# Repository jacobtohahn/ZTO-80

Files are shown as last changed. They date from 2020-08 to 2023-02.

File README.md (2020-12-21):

# ZTO-80
The ZTO-80 is a capable and highly expandable line of Z80 computers and peripherals.

[Hackaday](https://hackaday.io/project/167253-zto-80-modular-computer-system)

## Design
The ZTO-80 is built around the Zilog Z80 CPU, which was designed in 1976. It is still in production today, and, like the 6502, has found its place among hobbyists, particularly within the scope of vintage computing.

The system has two main designs: the SBC and the Modular System.
The ZTO-80 SBC is perfect for those wanting to get started developing with the Z80, both in hardware and software, while the Modular System is built from the ground up to be fully customizable, making it the perfect prototyping environment for more experienced developers.

### SBC
The ZTO-80 Single Board Computer, as the name implies, consists of only one PCB containing all essential system ICs along with I/O. This makes it cheaper and more compact than a multi-board system, with the downside being that it lacks the flexibility and customization it would have otherwise. My design addresses this downside by providing as many on-board features as possible, while allowing customization through configuration headers and an expansion bus.

#### SBC Features:
- CPU: Zilog Z80, running at 4-20MHz (depending on the model and your crystal choice)
- Memory:
  - RAM: 32K
  - ROM: 32K (with optional BASIC interpreter)
- I/O:
  - SIO:
    - Two serial channels with programmable baud rates
  - PIO:
    - Two 8-bit parallel ports, one with a darlington transistor array for high current output
  - CTC:
    - Four timers with external triggers

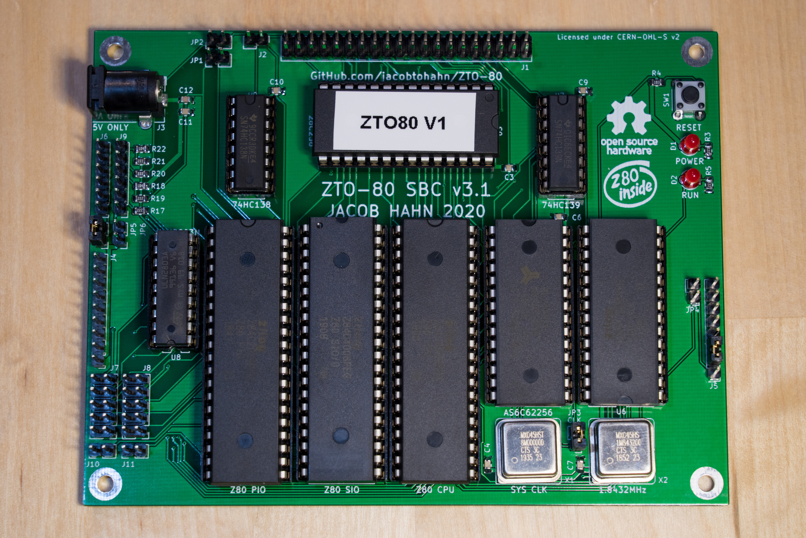
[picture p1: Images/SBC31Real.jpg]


### Modular System
The ZTO-80 Modular System is a multi-board system allowing ultimate customization and expansion. The system is built out of *modules* and a *backplane*. The modules contain individual pieces of a ZTO-80 computer system (such as the CPU, memory, serial I/O, etc). The backplane provides power and ties all of the modules together. A bus provides a standardized interface for modules to communicate with each other and connect to the backplane.

The main advantage of a modular system is flexiblilty. A user can install or remove individual features, or can create new features in the form of modules. This allows rapid prototyping and troubleshooting. Also, due to increased board space, more customization options can be implemented into individual modules.

Currently, work on the modular system is paused while I finish designing and testing the latest version of the SBC.

#### Official ZTO-80 Modular System modules:
- ZTO-80 Backplane 5
- ZTO-80 CPU
- ZTO-80 Memory
- ZTO-80 SIO
- ZTO-80 PIO (to be designed)
- ZTO-80 CTC

## How I use this repository
This repository keeps all of the PCB files and code for the ZTO-80. To keep things simple for me, I will update this repository each time I make a major change to an aspect of the design, either to the PCB or the code. I will also release minor fixes to the design.

## Contact
If you need to contact me for any reason, the best way is through my email, jtohahn@gmail.com.

You can also try to reach me through a private message on Hackaday.io, but there is no guarantee that I will see it.

## License
Copyright Jacob Hahn 2020.

This source describes Open Hardware and is licensed under the CERN-OHLS v2.
You may redistribute and modify this hardware and make products
using it under the terms of the CERN-OHL-S v2 (https:/cern.ch/cern-ohl).
This hardware is distributed WITHOUT ANY EXPRESS OR IMPLIED
WARRANTY, INCLUDING OF MERCHANTABILITY, SATISFACTORY QUALITY
AND FITNESS FOR A PARTICULAR PURPOSE. Please see the CERN-OHL-S v2
for applicable conditions.

Source location: https://github.com/jacobtohahn/ZTO-80

This documentation is released under the Attribution-ShareAlike 4.0 International License and is copyright Jacob Hahn 2020. You may use and share this documentation under the terms of the license, found here: https://creativecommons.org/licenses/by-sa/4.0/.

Please note that the CC-BY-SA License only applies to this project's documentation. Any other files, such as design files, are licensed under the terms of the CERN-OHL-S v2 license, as described above.

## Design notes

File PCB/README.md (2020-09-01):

# PCB
This directory contains the PCB files that I have created in KiCad so far, sorted as SBC PCBs and Modular System PCBs, along with any supporting documentation. The Modular System subdirectory contains a template for creating your own modules. See the READMEs in each subdirectory to get specific instructions for each board.

## Modular System Requirements
The three required boards for a working ZTO-80 Modular System are the Backplane, CPU board, and Memory board. Either the SIO or PIO board is required for output. The rest of the boards are optional and simply add additional features.

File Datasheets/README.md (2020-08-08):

# Datasheets
The subdirectories of this folder contain PDF datasheets for any ICs used.

Keep in mind that some pins may have slightly different names than what I used in my schematics, but it should be easy to tell which corresponds with which.

All datasheets included are not written by me and are copyrighted by their respective authors.

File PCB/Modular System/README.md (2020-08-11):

## Modular System PCBs
The subfolders in this directory contain the KiCad project files and additional files for Modular System boards. Look in each subfolder for information on each board and files.

## Component Notes
Unless stated otherwise in a README or silkscreen, always use CMOS ICs to build your system.

To bridge jumpers, I recommend using standard 0.1 in. jumper shunts.

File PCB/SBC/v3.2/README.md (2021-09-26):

# ZTO-80 SBC
This folder contains all the KiCad files for ZTO-80 SBC v3.2, along with an additional files and documentation.

This folder is a work in progress. The Getting Started guide has not been created yet. Check back soon!

## Additional files and subdirectories
- **PDF**: A subdirectory containing PDF files of the schematic and PCB.
- **Getting Started with the ZTO-80 SBC v3.2.pdf**: A getting started guide for the SBC v3.2.

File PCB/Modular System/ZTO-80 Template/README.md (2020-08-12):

# ZTO-80 Module Template
This directory contains a template file for creating your own ZTO-80 Modular System boards. There are comments in the PCB file itself, but this file will elaborate on some of them and add some design considerations.

## PCB Comments

### Module Title
This is the main title of the module, located on the front silkscreen of the board.
In general, you should try and keep the title short enough that the text is shorter than the width of the header below.

### Version
The revision of the PCB design, located on the front silkscreen of the board.
Start with v1.0.

### Designer and Year
The name of the board designer and the year the revision was made, located on the front silkscreen of the board.

### Module Reference
This text on the front silkscreen provides a quick way to find or identify a module when it is in a backplane. 
Oftentimes, other modules will prevent you from being able to see the main title of the module, so this reference is located at the top corner of the PCB, where it will not be blocked. 

### JLCPCB PN Reference
This text, located on the back silkscreen, is used if you choose to have your boards manufactured by JLCPCB.
It lets them know where you would like the Product Number text to be silkscreened. If you don't have the boards manufactured by JLCPCB, be sure to remove it!

### Component Keepout
This keepout lets your module be compatible with an enclosure that is currently in development.
There is a slot which the board edge fits into, so if there are any components within the area on the front or back of the PCB, the board will not be compatible with the enclosure.

## General Design Considerations
- When designing boards, I use a 25 mil grid. I recommend using the same.
- All of my boards use 10 mil trace/space. This is compatible with most fabs and also is small enough to fit traces between pins.

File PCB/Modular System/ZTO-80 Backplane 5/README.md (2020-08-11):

# ZTO-80 Backplane 5
This is the main backplane for the ZTO-80 Modular System. It includes 5 module slots, a power input jack and LED, a reset button, two headers for connecting an external power LED and reset switch, and six M3 mounting holes.

The power input supports 5V only. Anything over 5.5 volts could damage or destroy some ICs.

## Additional Files
- **PDF**: A subdirectory containing PDF files of the schematic and PCB.

## Component Notes
The ZTO-80 bus header slots should be female sockets.

I recommend using pan-head M3 machine screws with a washer to fasten the board with the mounting holes.

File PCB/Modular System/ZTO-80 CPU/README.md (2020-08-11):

# ZTO-80 CPU
This is the CPU module for the ZTO-80 Modular System, containing the Z80 CPU, system clock, reset button, address and data buffers, and a header for CPU signals.

## Additional Files
- **PDF**: A subdirectory containing PDF files of the schematic and PCB.

## Component Notes
It is recommended to use a CMOS Z80 and 74HCT logic ICs on this board.

While Z80s overclock well, it is recommended that the max clock speed matches the CPU's rated speed.

Use two pin headers as jumpers on this board.

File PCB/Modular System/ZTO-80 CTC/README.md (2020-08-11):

# ZTO-80 CTC
This is the CTC (Counter-Timer Circuit) board for the ZTO-80 Modular system. It contains the CTC, a DIP switch for setting the address, jumpers for setting the CTC configuration, and a pin header for outputting the CTC signals.

## Additional Files
- **PDF**: A subdirectory containing PDF files of the schematic and PCB.

## Component Notes
Use two pin male headers as the jumpers on this board.

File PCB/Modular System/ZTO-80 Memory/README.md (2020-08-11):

## ZTO-80 Memory
This is the memory board for the ZTO-80 Modular System. It contains the RAM and ROM chips.

## Additional Files
- **PDF**: A subdirectory containing PDF files of the schematic and PCB.

## Component Notes
The RAM chip should be 32K, and the ROM chip should be 32K.

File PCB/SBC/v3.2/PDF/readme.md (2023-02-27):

# !!! WARNING !!!
## These PDF files are not up to date while I rework my PDF generation workflow. To see the latest PCB, download and open the KiCAD PCB file.

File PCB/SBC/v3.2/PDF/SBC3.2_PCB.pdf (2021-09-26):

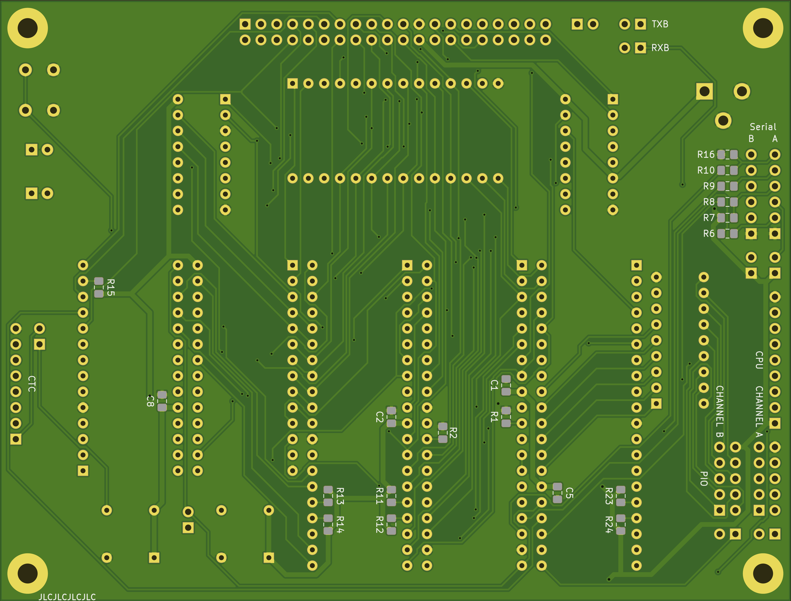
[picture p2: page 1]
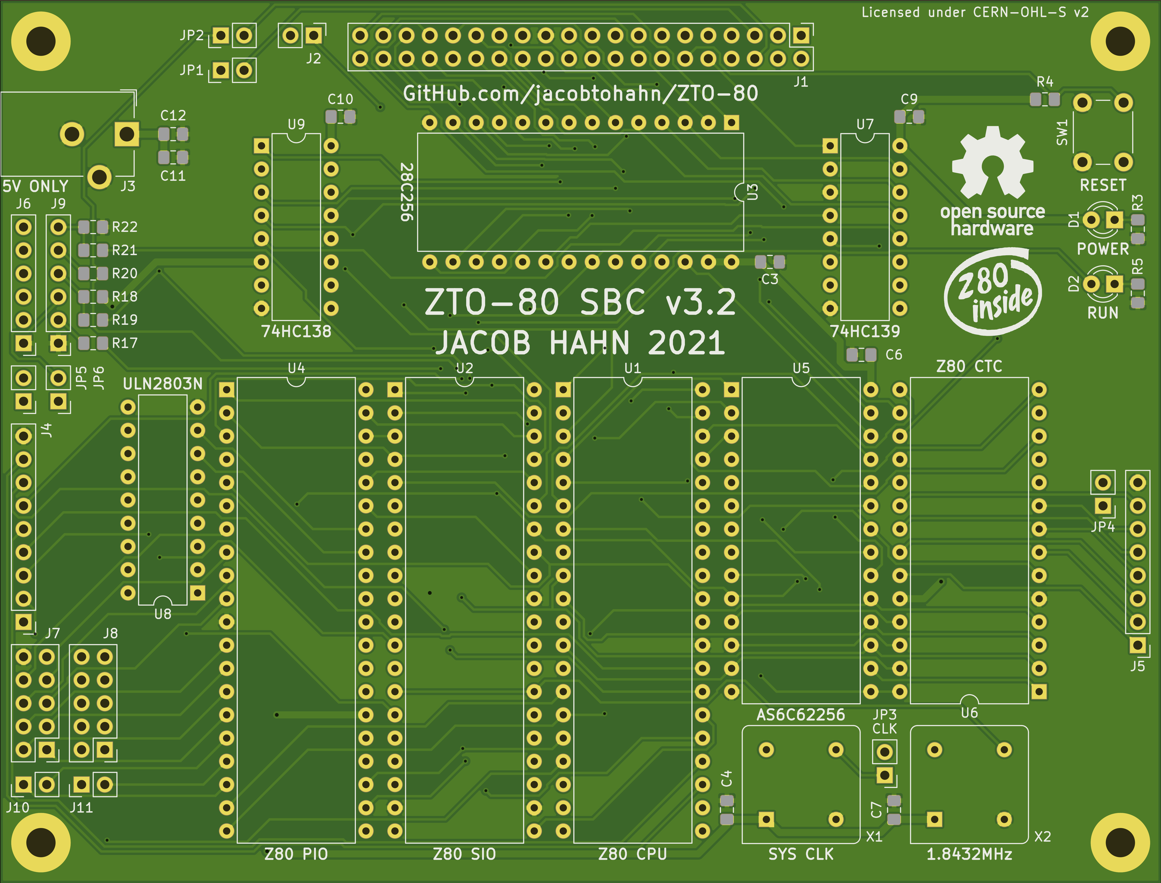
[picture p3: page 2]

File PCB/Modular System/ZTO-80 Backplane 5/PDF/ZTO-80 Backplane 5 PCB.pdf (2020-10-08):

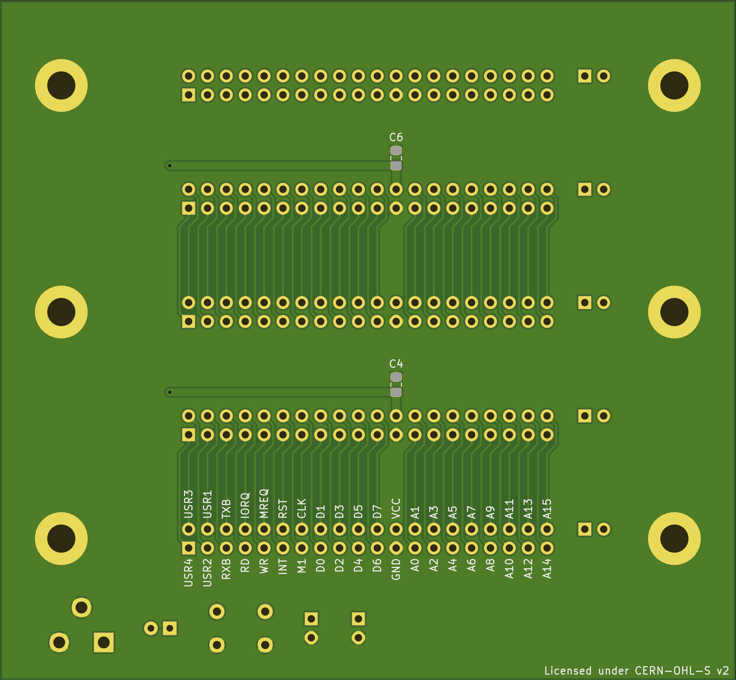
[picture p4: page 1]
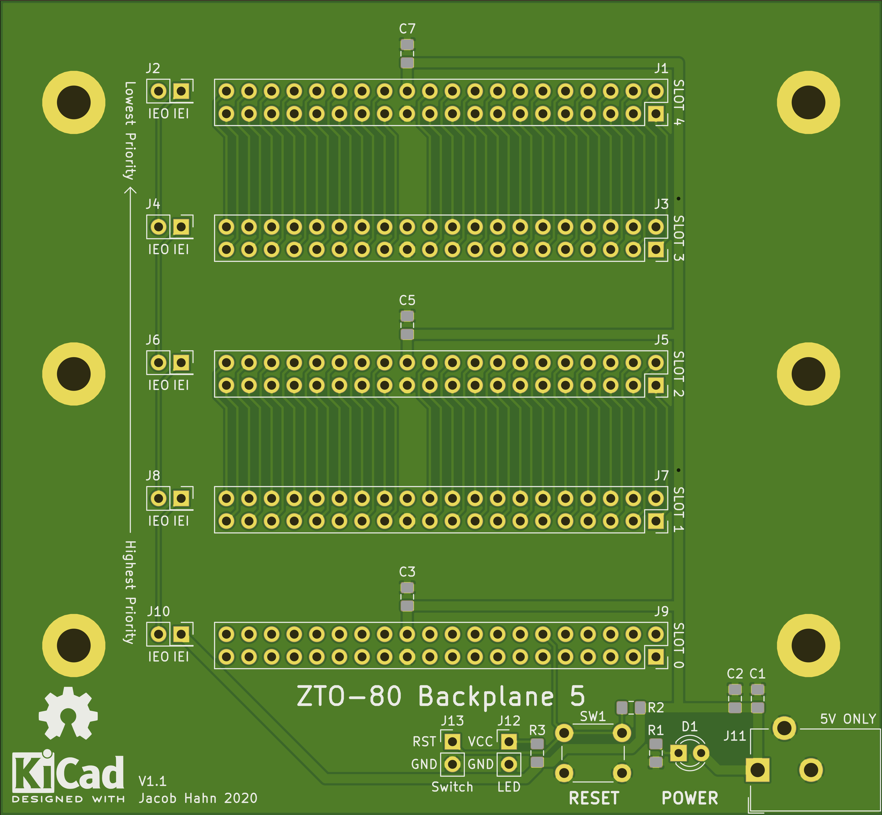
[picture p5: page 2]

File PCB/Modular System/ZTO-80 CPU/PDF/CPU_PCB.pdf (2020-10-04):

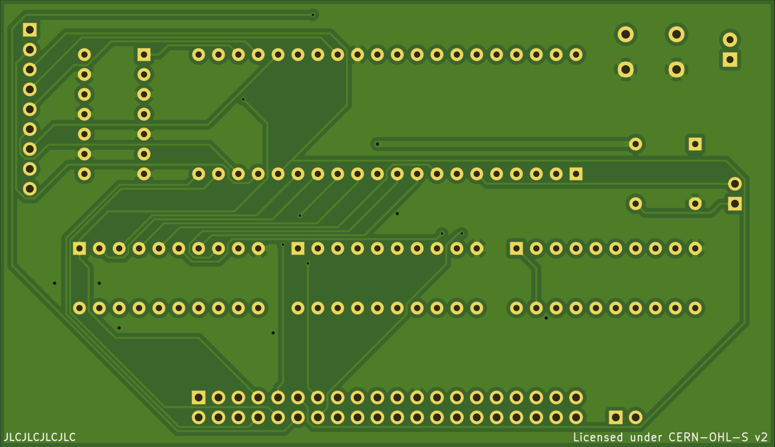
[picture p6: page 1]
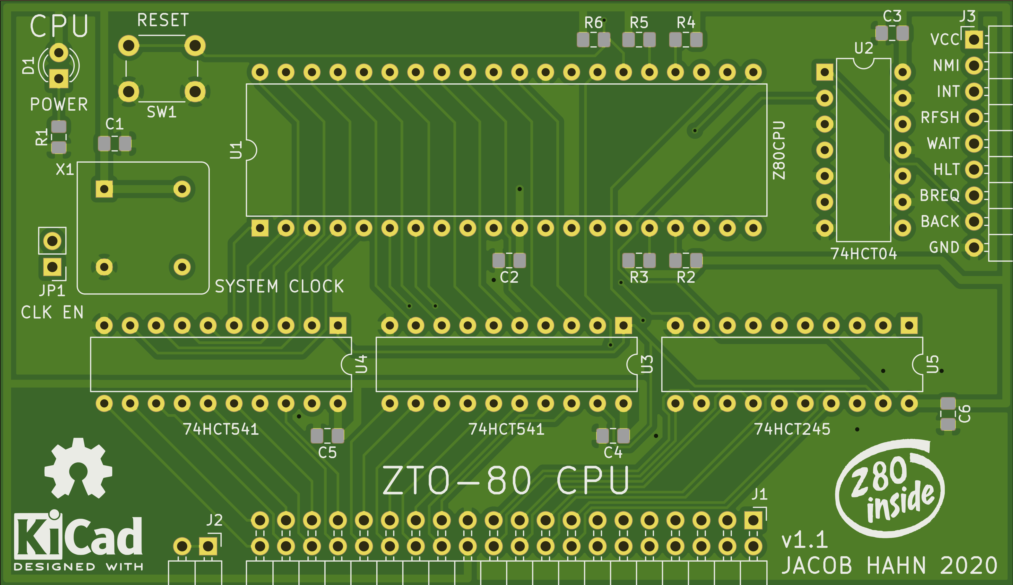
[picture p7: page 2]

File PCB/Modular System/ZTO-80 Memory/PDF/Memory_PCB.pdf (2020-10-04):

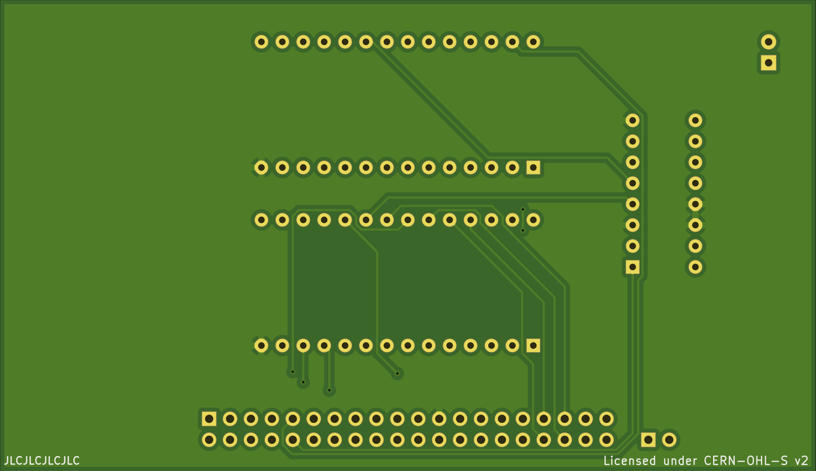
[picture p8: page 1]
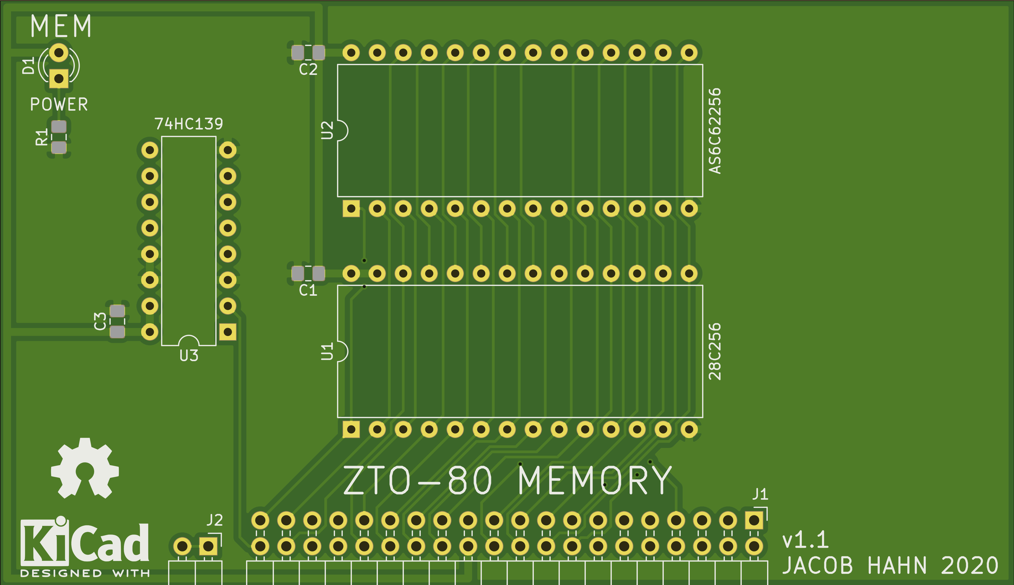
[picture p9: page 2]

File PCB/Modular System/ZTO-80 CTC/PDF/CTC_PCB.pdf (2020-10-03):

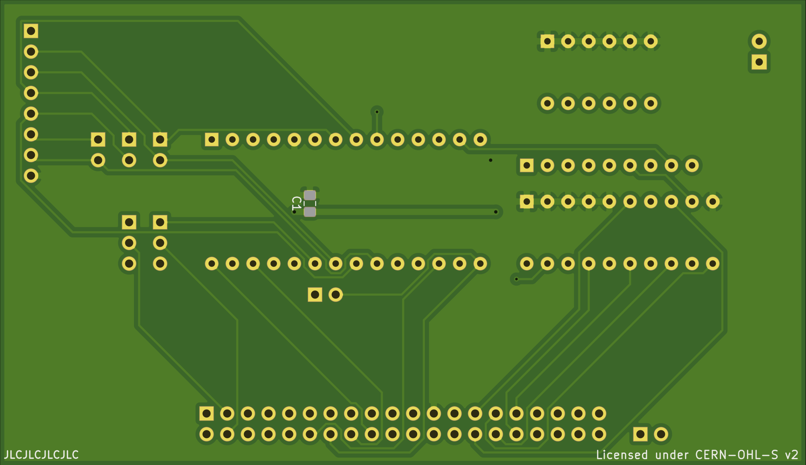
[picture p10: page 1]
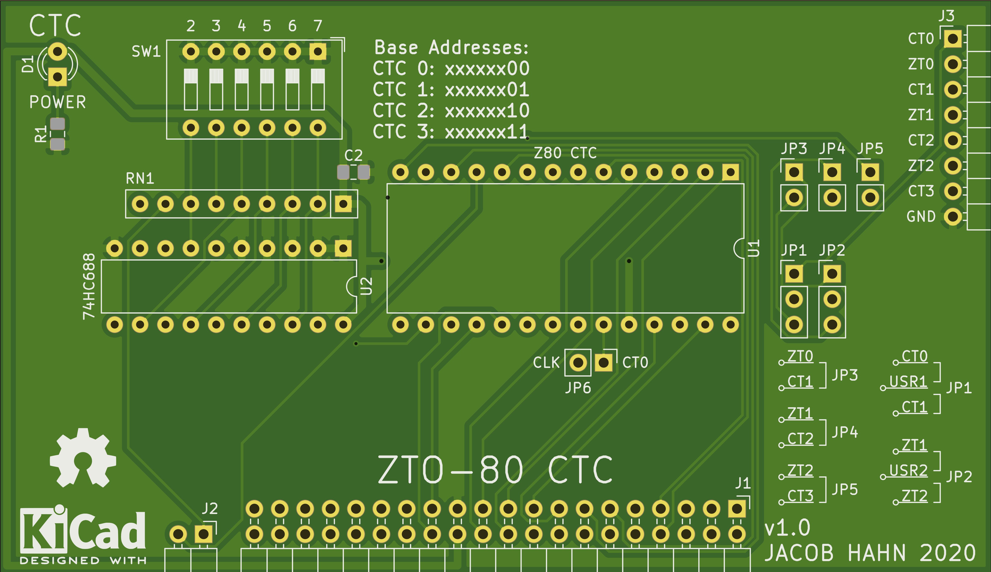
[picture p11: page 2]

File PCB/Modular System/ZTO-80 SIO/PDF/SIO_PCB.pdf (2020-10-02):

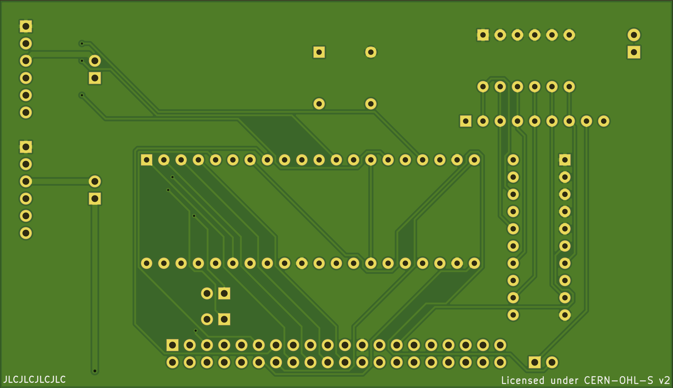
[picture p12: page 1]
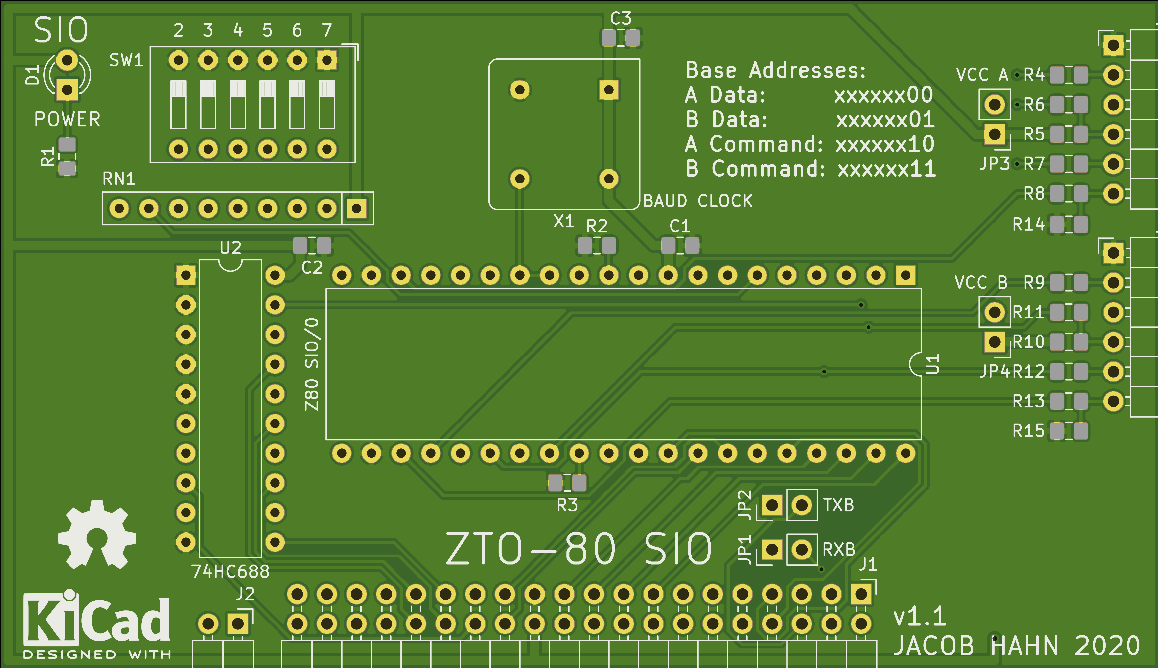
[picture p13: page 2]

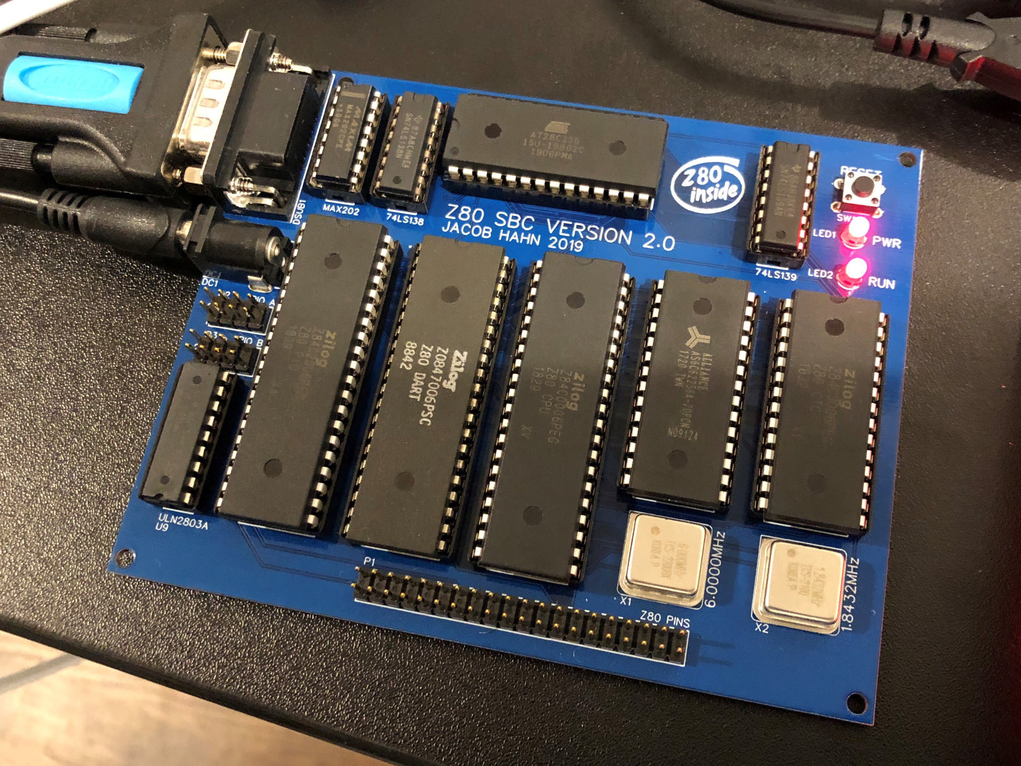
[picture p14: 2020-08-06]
Images/SBCv2.jpg

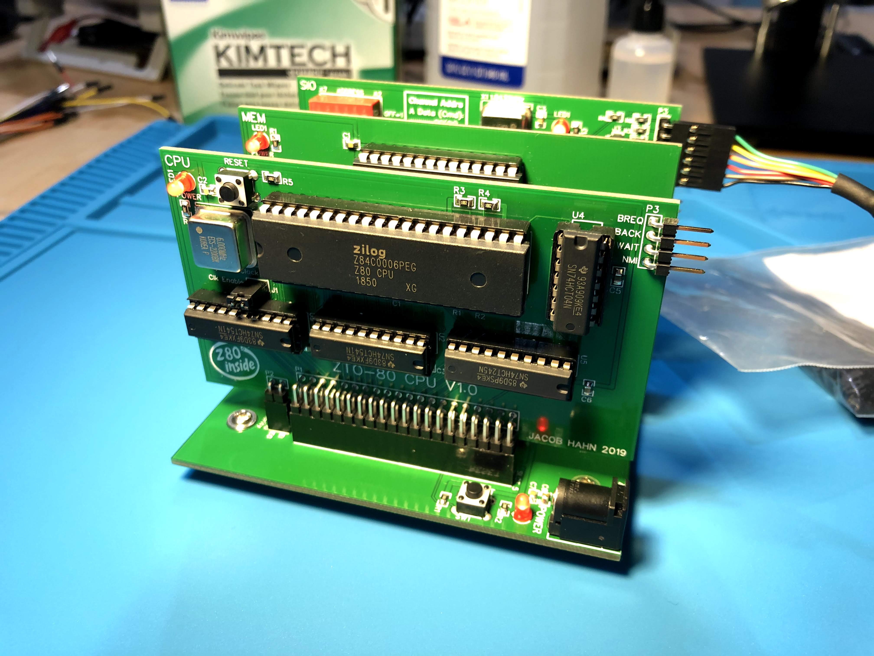
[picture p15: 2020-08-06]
Images/Mod3.jpg

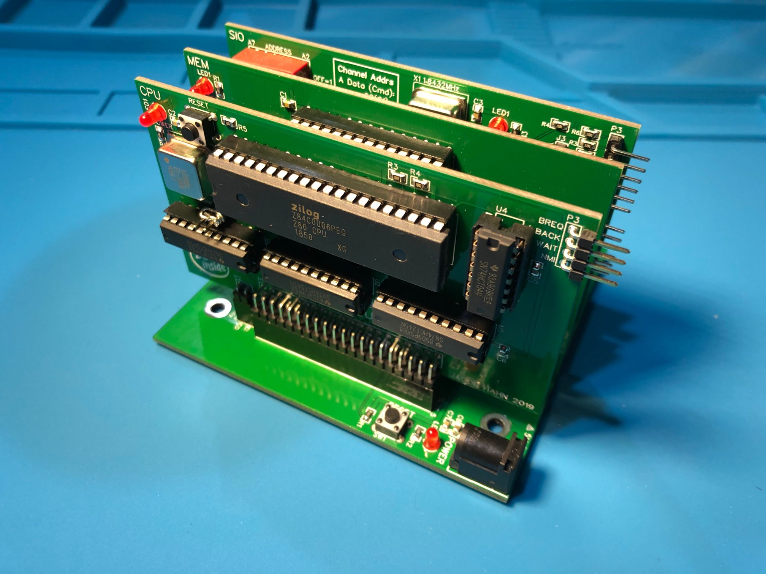
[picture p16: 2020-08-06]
Images/Mod1.jpg

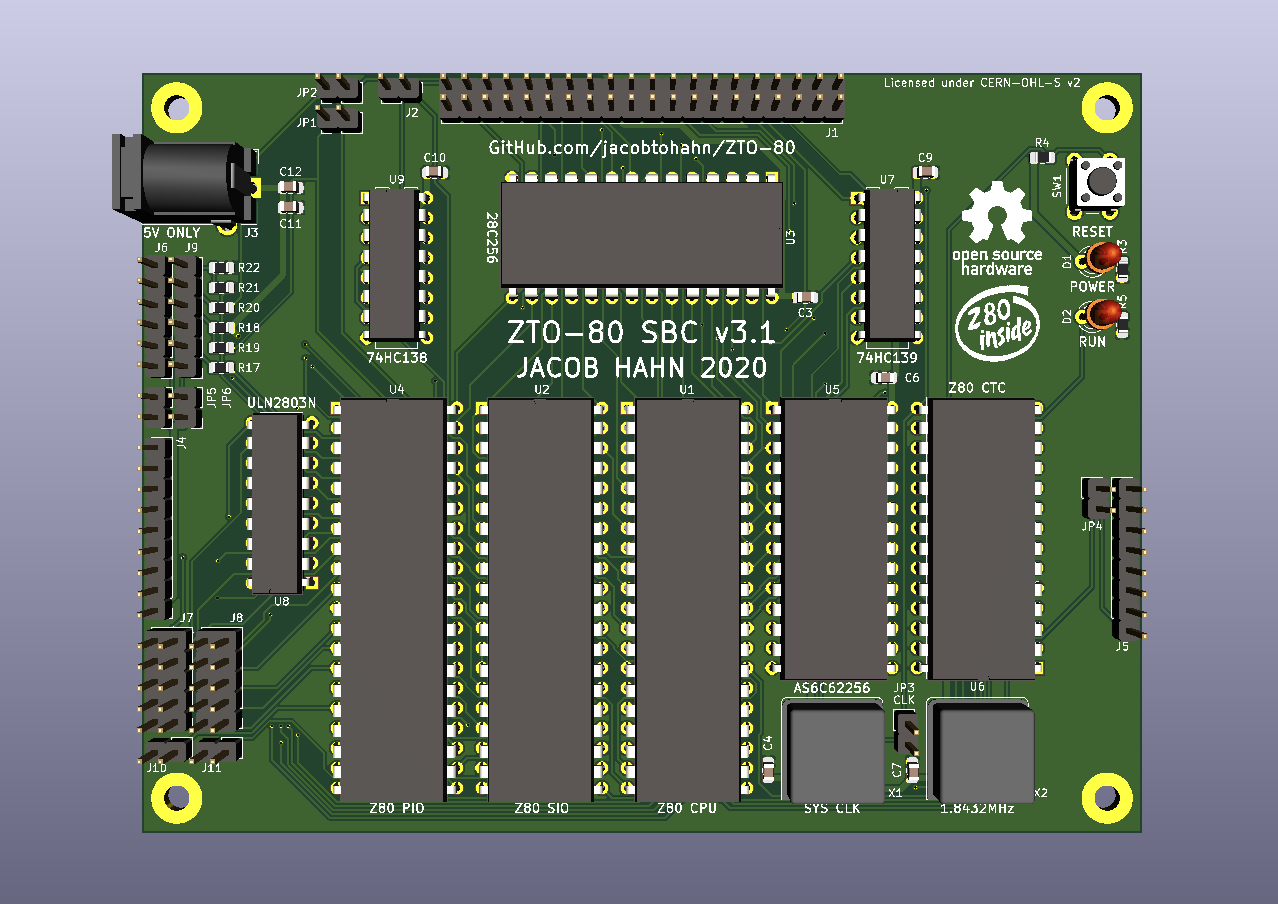
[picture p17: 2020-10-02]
Images/SBC31.PNG

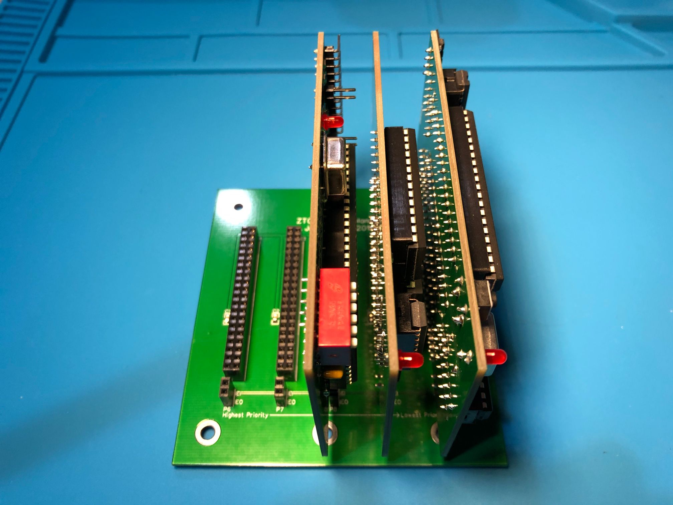
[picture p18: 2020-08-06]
Images/Mod2.jpg

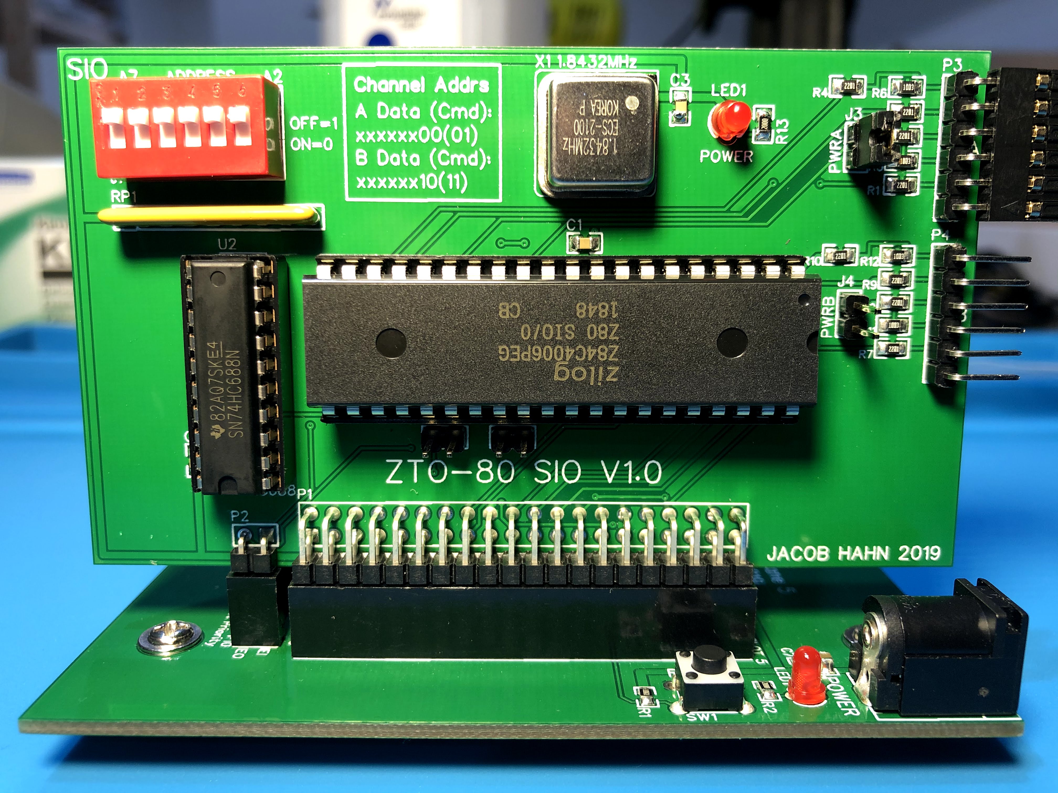
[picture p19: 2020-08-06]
Images/SIO.jpg

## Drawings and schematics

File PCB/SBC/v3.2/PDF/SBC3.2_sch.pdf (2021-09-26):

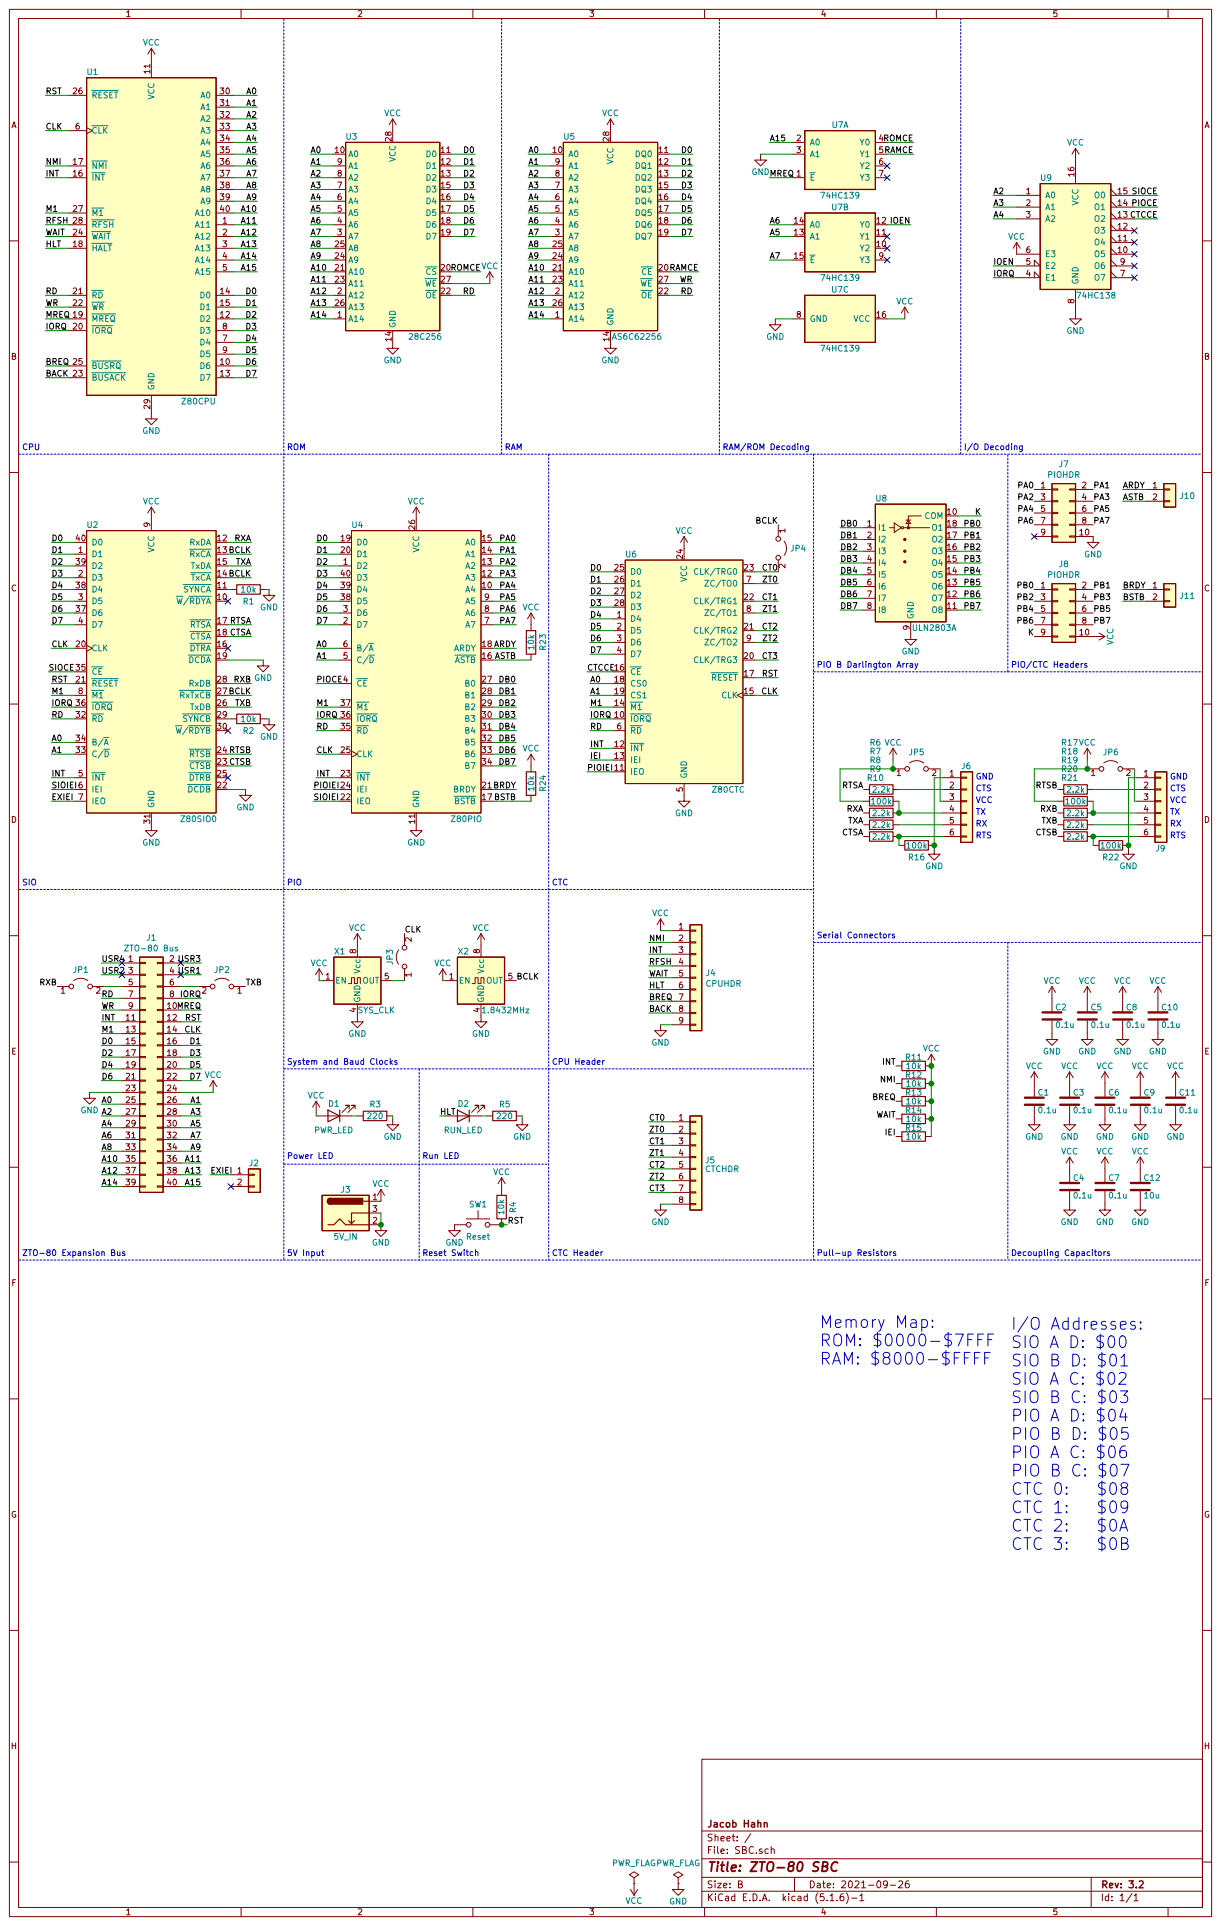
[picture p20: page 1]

5 RD 6 ZC/TO0 7 ZC/TO1 8 ZC/TO2 9 U6 Z80CTC

PIO B Darlington Array CTC

PIO/CTC Headers Serial Connectors

File: SBC.sch Sheet: / Jacob Hahn

Id: 1/1 Title: ZTO-80 SBC

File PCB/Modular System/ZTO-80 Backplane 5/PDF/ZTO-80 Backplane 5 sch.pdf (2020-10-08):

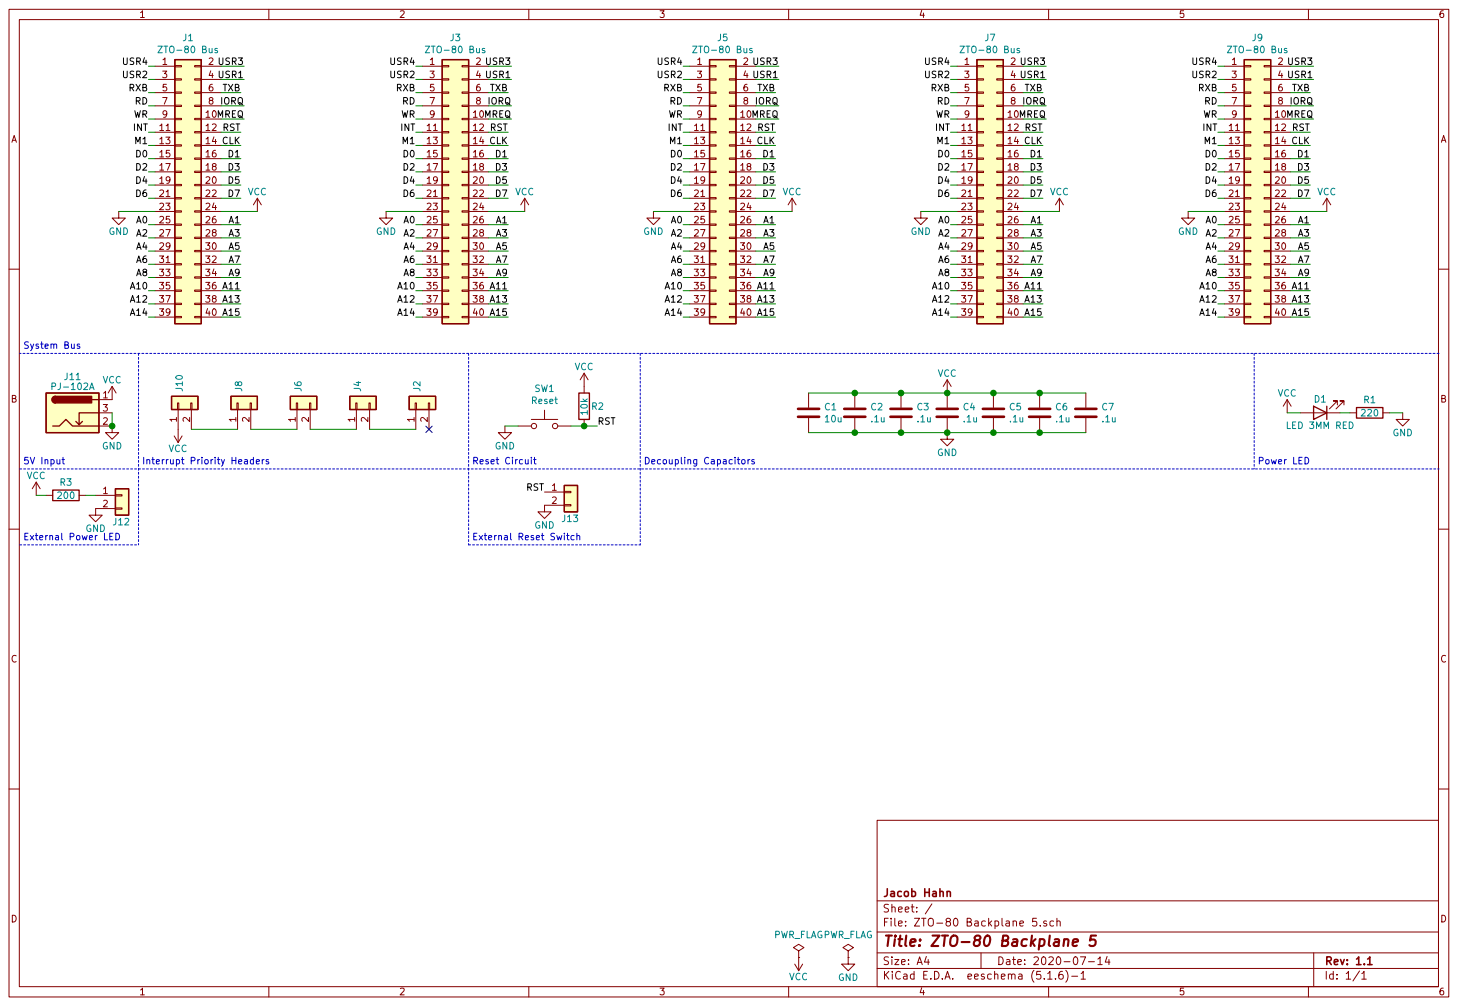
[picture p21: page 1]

.1u VCC GND
System Bus External Power LED

File: ZTO-80 Backplane 5.sch Sheet: / Jacob Hahn

Id: 1/1 Title: ZTO-80 Backplane 5

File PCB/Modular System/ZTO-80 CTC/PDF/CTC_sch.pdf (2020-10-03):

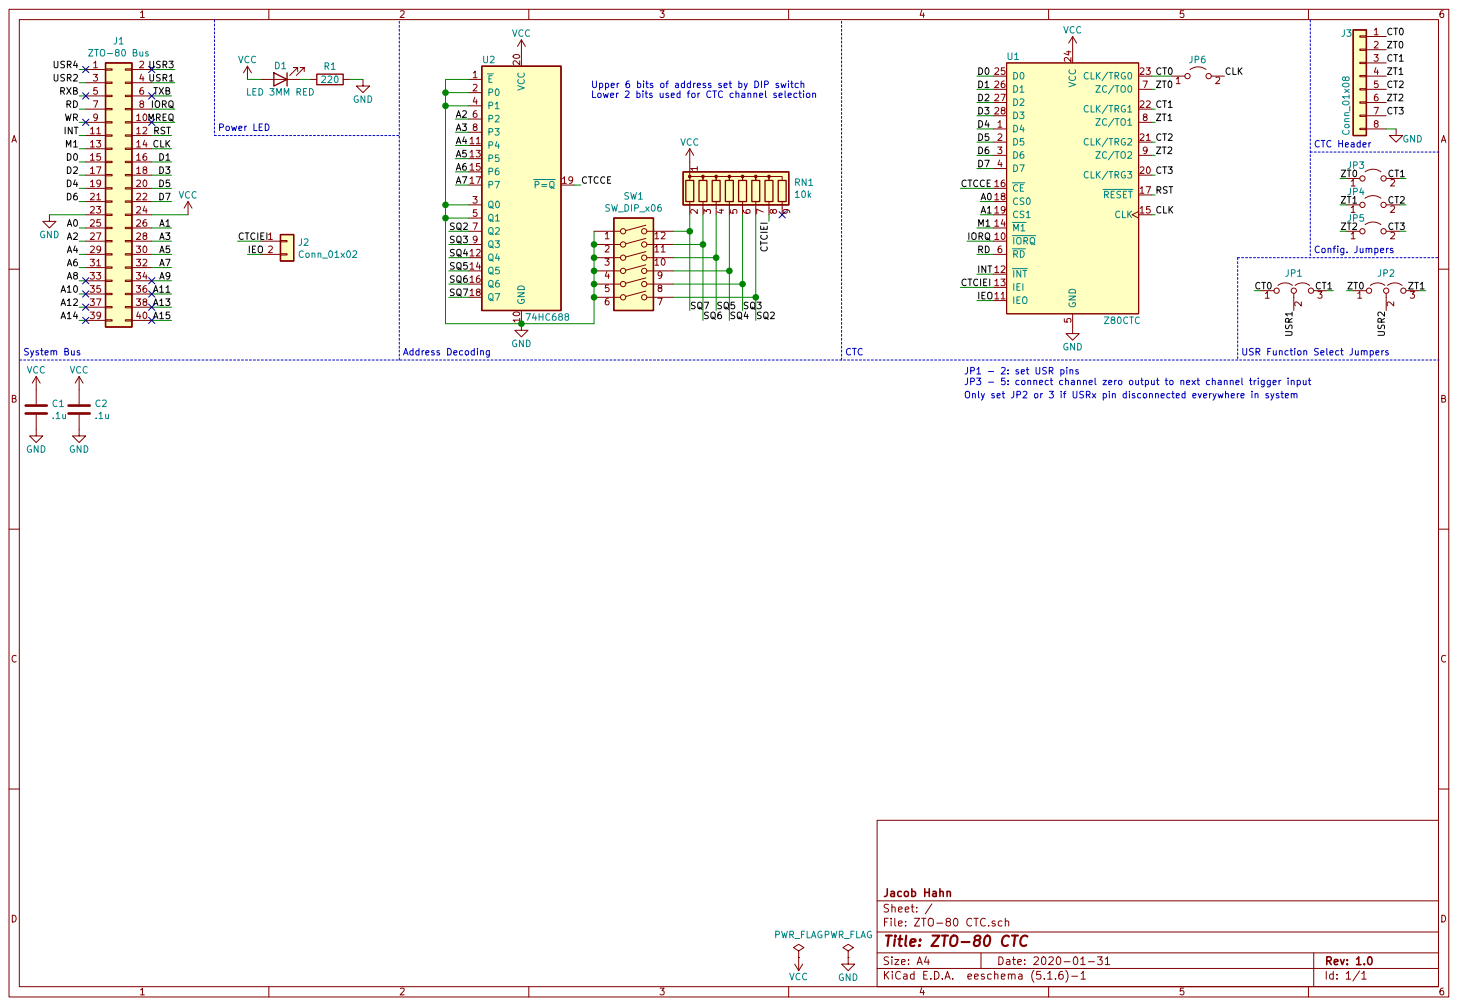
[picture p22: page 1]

Lower 2 bits used for CTC channel selection Upper 6 bits of address set by DIP switch

File: ZTO-80 CTC.sch Sheet: / Jacob Hahn

Id: 1/1 Title: ZTO-80 CTC

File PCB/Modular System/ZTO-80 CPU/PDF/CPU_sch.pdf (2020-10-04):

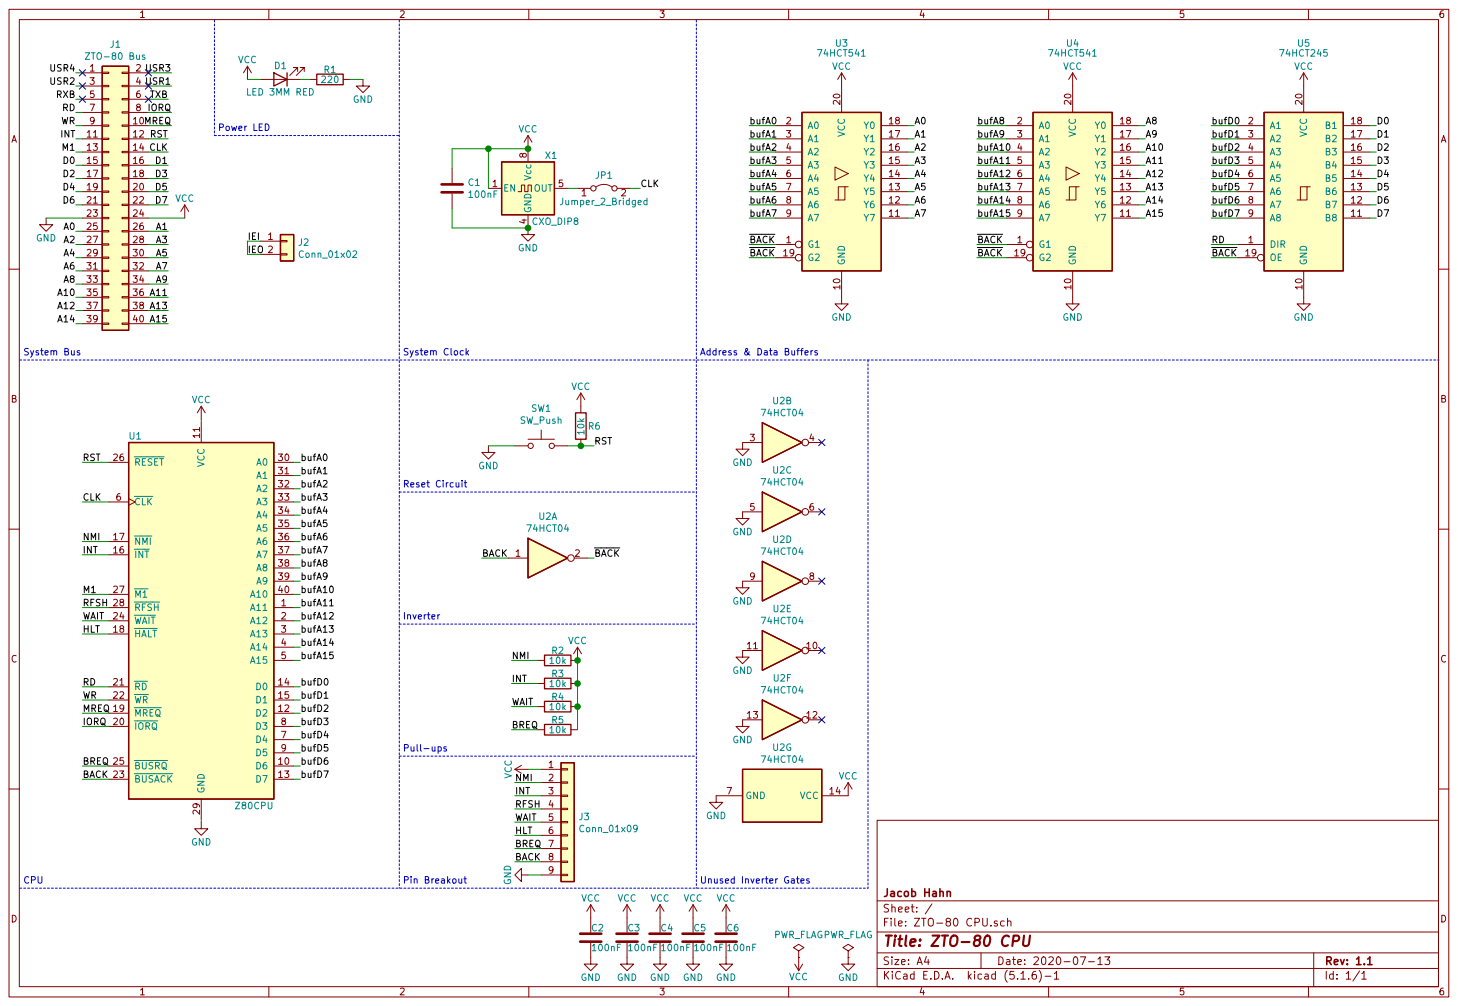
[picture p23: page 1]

File: ZTO-80 CPU.sch Sheet: / Jacob Hahn

Id: 1/1 Title: ZTO-80 CPU

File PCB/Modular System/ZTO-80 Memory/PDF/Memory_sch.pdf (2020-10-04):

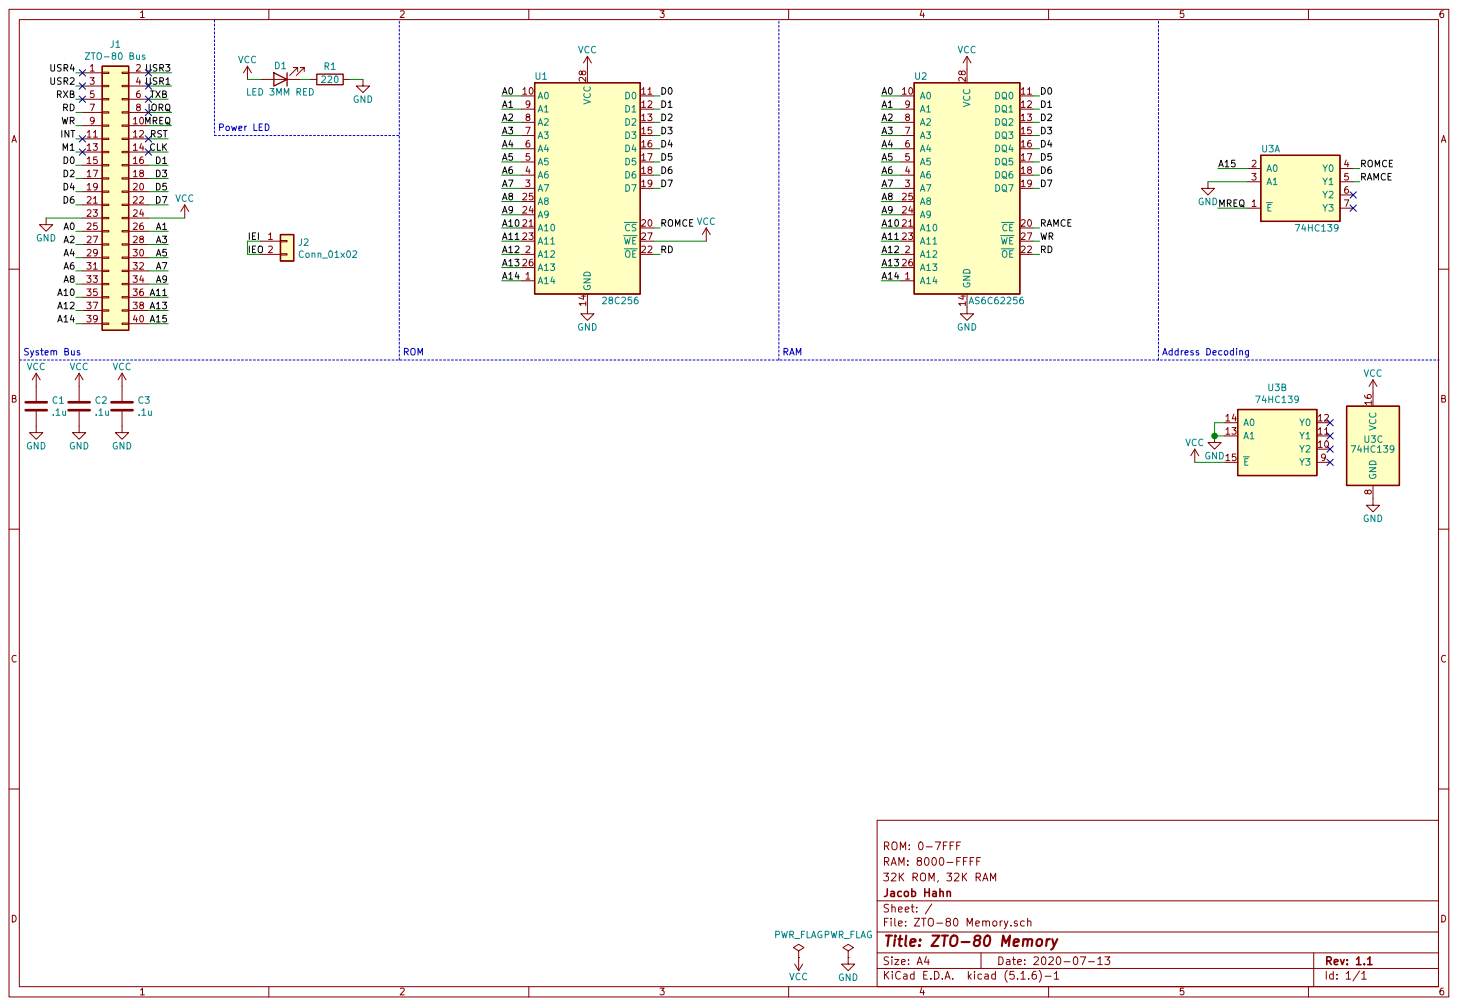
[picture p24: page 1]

32K ROM, 32K RAM
File: ZTO-80 Memory.sch Sheet: / Jacob Hahn

Id: 1/1 Title: ZTO-80 Memory

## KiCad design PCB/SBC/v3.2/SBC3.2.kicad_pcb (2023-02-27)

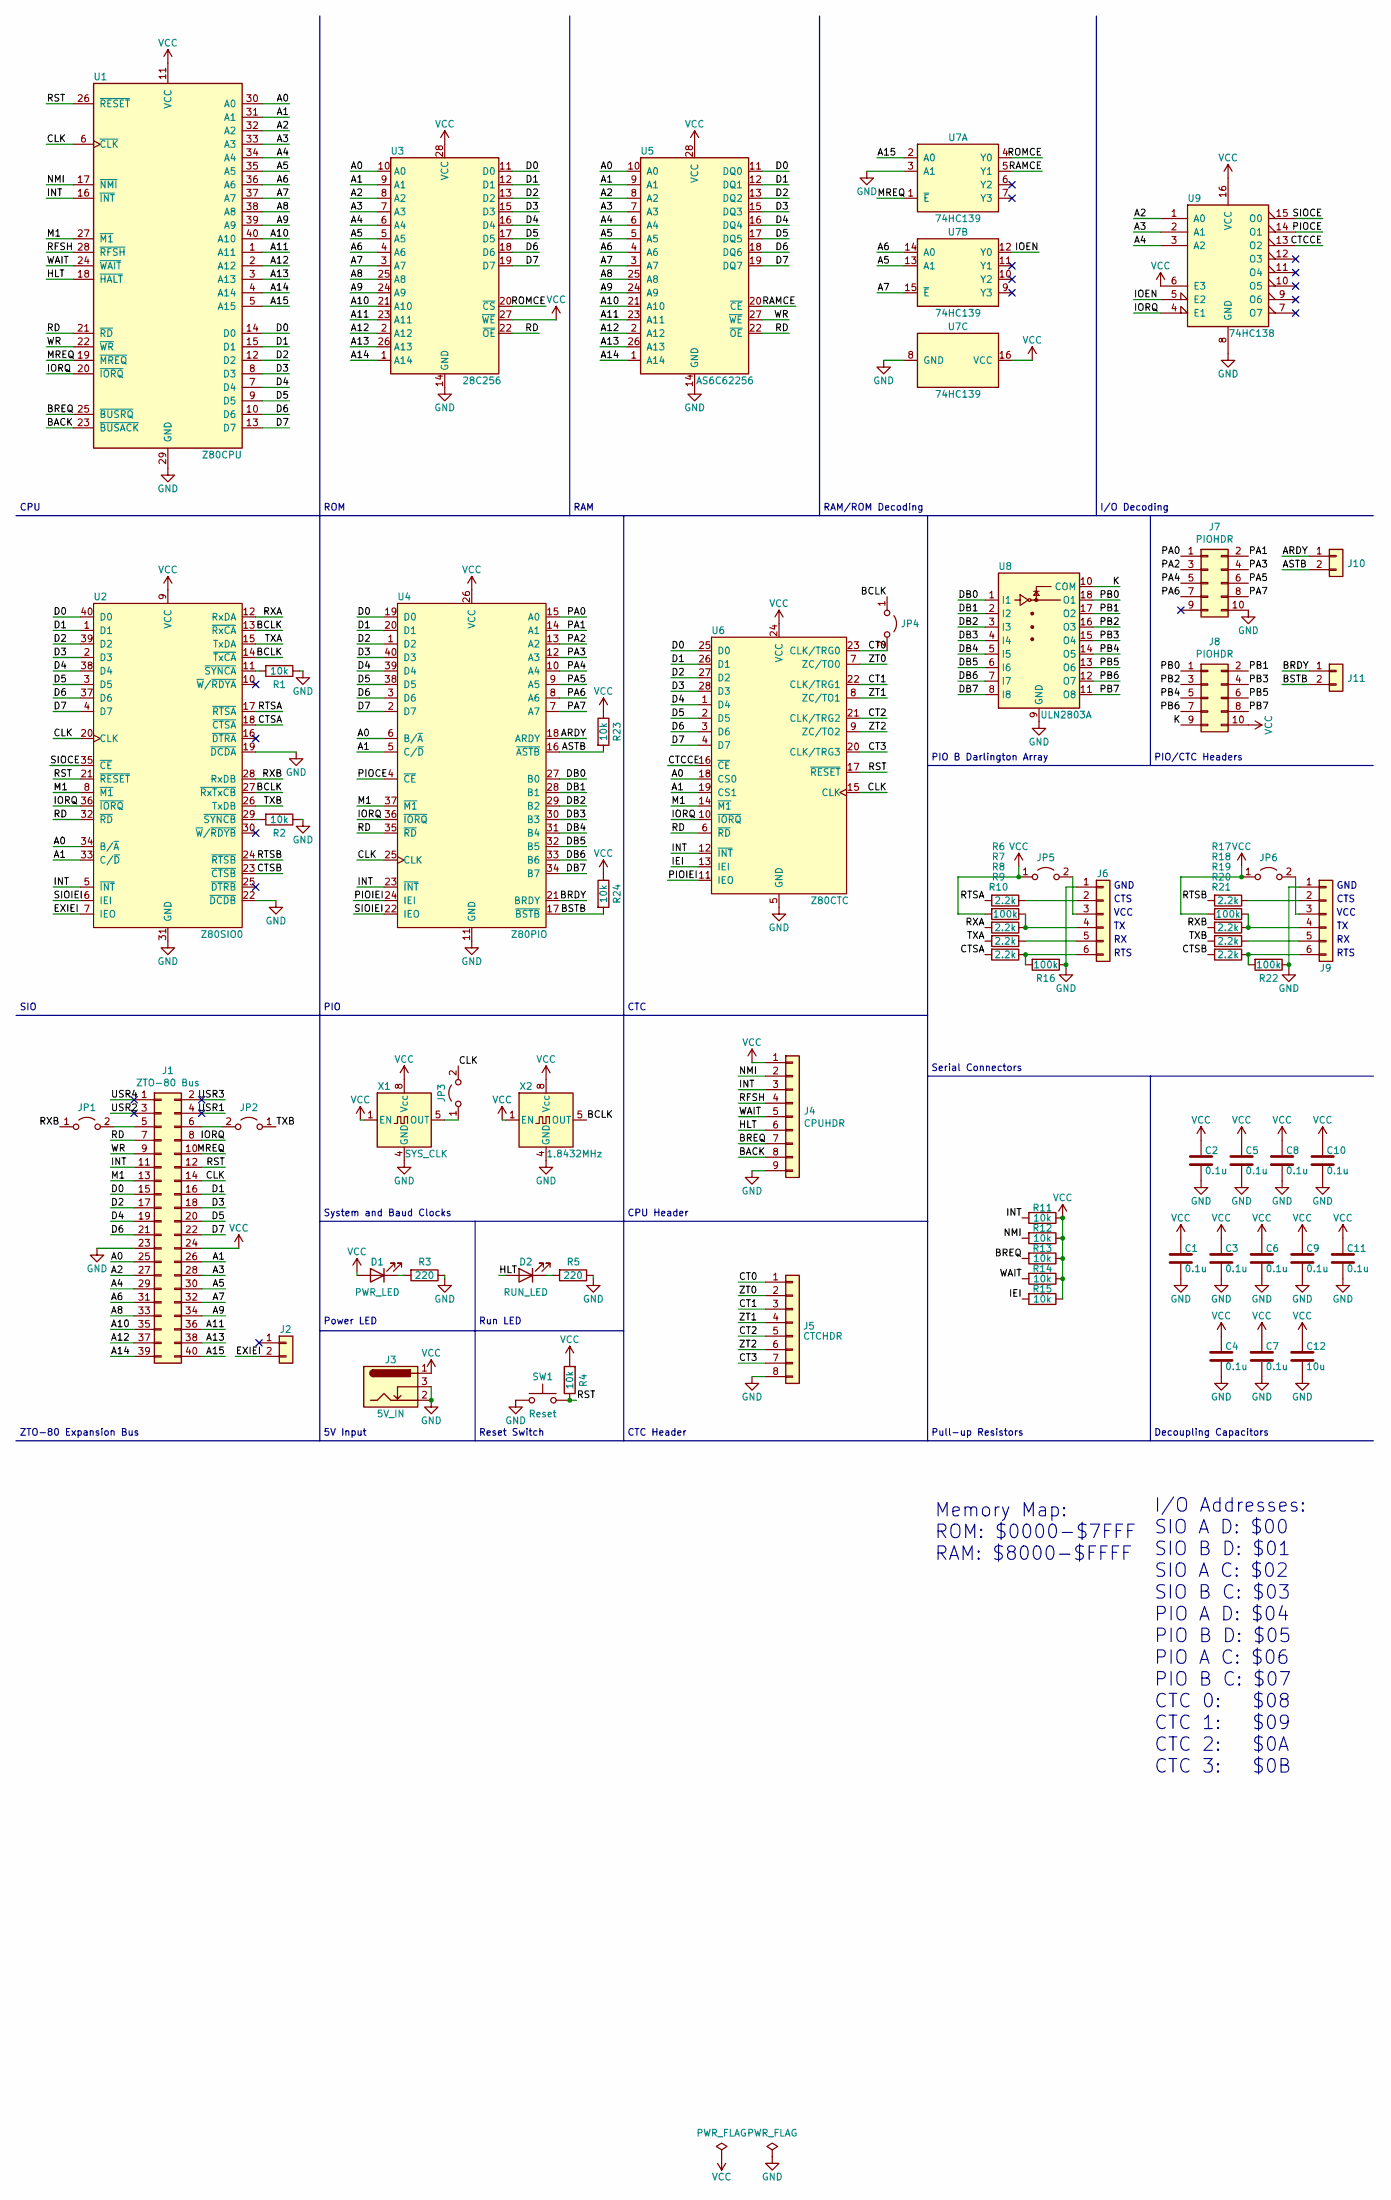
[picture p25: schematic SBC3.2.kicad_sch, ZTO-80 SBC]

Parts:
C1, C2, C3, C4, C5, C6, C7, C8, C9, C10, C11: 0.1u; C_0805_2012Metric_Pad1.15x1.40mm_HandSolder
C12: 10u; C_0805_2012Metric_Pad1.15x1.40mm_HandSolder
D1: PWR_LED; LED_D3.0mm
D2: RUN_LED; LED_D3.0mm
J1: ZTO-80 Bus; PinHeader_2x20_P2.54mm_Vertical
J2, J10, J11: Conn_01x02; PinHeader_1x02_P2.54mm_Vertical
J3: 5V_IN; BarrelJack_CUI_PJ-102A_Horizontal
J4: CPUHDR; PinHeader_1x09_P2.54mm_Vertical
J5: CTCHDR; PinHeader_1x08_P2.54mm_Vertical
J6, J9: SIOHDR; PinHeader_1x06_P2.54mm_Vertical
J7, J8: PIOHDR; PinHeader_2x05_P2.54mm_Vertical
JP1, JP2, JP3, JP4, JP5, JP6: Jumper_2_Open; PinHeader_1x02_P2.54mm_Vertical
R1, R2, R4, R11, R12, R13, R14, R15, R23, R24: 10k; R_0805_2012Metric_Pad1.15x1.40mm_HandSolder
R3, R5: 220; R_0805_2012Metric_Pad1.15x1.40mm_HandSolder
R6, R8, R9, R10, R17, R19, R20, R21: 2.2k; R_0805_2012Metric_Pad1.15x1.40mm_HandSolder
R7, R16, R18, R22: 100k; R_0805_2012Metric_Pad1.15x1.40mm_HandSolder
SW1: Reset; SW_PUSH_6mm
U1: Z80CPU; DIP-40_W15.24mm
U2: Z80SIO0; DIP-40_W15.24mm
U3: 28C256; DIP-28_W15.24mm
U4: Z80PIO; DIP-40_W15.24mm
U5: AS6C62256; DIP-28_W15.24mm
U6: Z80CTC; DIP-28_W15.24mm
U7: 74HC139; DIP-16_W7.62mm
U8: ULN2803A; DIP-18_W7.62mm
U9: 74HC138; DIP-16_W7.62mm
X1: SYS_CLK; Oscillator_DIP-8
X2: 1.8432MHz; Oscillator_DIP-8

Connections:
/A0: J1.25, U1.30 (A0), U2.34 (B/~A), U3.10 (A0), U4.6 (B/~A), U5.10 (A0), U6.18 (CS0)
/A1: J1.26, U1.31 (A1), U2.33 (C/~D), U3.9 (A1), U4.5 (C/~D), U5.9 (A1), U6.19 (CS1)
/A2: J1.27, U1.32 (A2), U3.8 (A2), U5.8 (A2), U9.1 (A0)
/A3: J1.28, U1.33 (A3), U3.7 (A3), U5.7 (A3), U9.2 (A1)
/A4: J1.29, U1.34 (A4), U3.6 (A4), U5.6 (A4), U9.3 (A2)
/A5: J1.30, U1.35 (A5), U3.5 (A5), U5.5 (A5), U7.13 (A1)
/A6: J1.31, U1.36 (A6), U3.4 (A6), U5.4 (A6), U7.14 (A0)
/A7: J1.32, U1.37 (A7), U3.3 (A7), U5.3 (A7), U7.15 (~E)
/A8: J1.33, U1.38 (A8), U3.25 (A8), U5.25 (A8)
/A9: J1.34, U1.39 (A9), U3.24 (A9), U5.24 (A9)
/A10: J1.35, U1.40 (A10), U3.21 (A10), U5.21 (A10)
/A11: J1.36, U1.1 (A11), U3.23 (A11), U5.23 (A11)
/A12: J1.37, U1.2 (A12), U3.2 (A12), U5.2 (A12)
/A13: J1.38, U1.3 (A13), U3.26 (A13), U5.26 (A13)
/A14: J1.39, U1.4 (A14), U3.1 (A14), U5.1 (A14)
/A15: J1.40, U1.5 (A15), U7.2 (A0)
/ARDY: J10.1, U4.18 (ARDY)
/ASTB: J10.2, R23.2, U4.16 (~ASTB)
/BACK: J4.8, U1.23 (~BUSACK)
/BCLK: JP4.1 (A), U2.13 (~RxCA), U2.14 (~TxCA), U2.27 (~RxTxCB), X2.5 (OUT)
/BRDY: J11.1, U4.21 (BRDY)
/BREQ: J4.7, R13.2, U1.25 (~BUSRQ)
/BSTB: J11.2, R24.2, U4.17 (~BSTB)
/CLK: J1.14, JP3.2 (B), U1.6 (~CLK), U2.20 (CLK), U4.25 (CLK), U6.15 (CLK)
/CT0: J5.1, JP4.2 (B), U6.23 (CLK/TRG0)
/CT1: J5.3, U6.22 (CLK/TRG1)
/CT2: J5.5, U6.21 (CLK/TRG2)
/CT3: J5.7, U6.20 (CLK/TRG3)
/CTCCE: U6.16 (~CE), U9.13 (O2)
/CTSA: R10.2, U2.18 (~CTSA)
/CTSB: R21.2, U2.23 (~CTSB)
/D0: J1.15, U1.14 (D0), U2.40 (D0), U3.11 (D0), U4.19 (D0), U5.11 (DQ0), U6.25 (D0)
/D1: J1.16, U1.15 (D1), U2.1 (D1), U3.12 (D1), U4.20 (D1), U5.12 (DQ1), U6.26 (D1)
/D2: J1.17, U1.12 (D2), U2.39 (D2), U3.13 (D2), U4.1 (D2), U5.13 (DQ2), U6.27 (D2)
/D3: J1.18, U1.8 (D3), U2.2 (D3), U3.15 (D3), U4.40 (D3), U5.15 (DQ3), U6.28 (D3)
/D4: J1.19, U1.7 (D4), U2.38 (D4), U3.16 (D4), U4.39 (D4), U5.16 (DQ4), U6.1 (D4)
/D5: J1.20, U1.9 (D5), U2.3 (D5), U3.17 (D5), U4.38 (D5), U5.17 (DQ5), U6.2 (D5)
/D6: J1.21, U1.10 (D6), U2.37 (D6), U3.18 (D6), U4.3 (D6), U5.18 (DQ6), U6.3 (D6)
/D7: J1.22, U1.13 (D7), U2.4 (D7), U3.19 (D7), U4.2 (D7), U5.19 (DQ7), U6.4 (D7)
/DB0: U4.27 (B0), U8.1 (I1)
/DB1: U4.28 (B1), U8.2 (I2)
/DB2: U4.29 (B2), U8.3 (I3)
/DB3: U4.30 (B3), U8.4 (I4)
/DB4: U4.31 (B4), U8.5 (I5)
/DB5: U4.32 (B5), U8.6 (I6)
/DB6: U4.33 (B6), U8.7 (I7)
/DB7: U4.34 (B7), U8.8 (I8)
/EXIEI: J2.2, U2.7 (IEO)
/HLT: D2.2 (A), J4.6, U1.18 (~HALT)
/IEI: R15.2, U6.13 (IEI)
/INT: J1.11, J4.3, R11.2, U1.16 (~INT), U2.5 (~INT), U4.23 (~INT), U6.12 (~INT)
/IOEN: U7.12 (Y0), U9.5 (E2)
/IORQ: J1.8, U1.20 (~IORQ), U2.36 (~IORQ), U4.36 (~IORQ), U6.10 (~IORQ), U9.4 (E1)
/K: J8.9, U8.10 (COM)
/M1: J1.13, U1.27 (~M1), U2.8 (~M1), U4.37 (~M1), U6.14 (~M1)
/MREQ: J1.10, U1.19 (~MREQ), U7.1 (~E)
/NMI: J4.2, R12.2, U1.17 (~NMI)
/PA0: J7.1, U4.15 (A0)
/PA1: J7.2, U4.14 (A1)
/PA2: J7.3, U4.13 (A2)
/PA3: J7.4, U4.12 (A3)
/PA4: J7.5, U4.10 (A4)
/PA5: J7.6, U4.9 (A5)
/PA6: J7.7, U4.8 (A6)
/PA7: J7.8, U4.7 (A7)
/PB0: J8.1, U8.18 (O1)
/PB1: J8.2, U8.17 (O2)
/PB2: J8.3, U8.16 (O3)
/PB3: J8.4, U8.15 (O4)
/PB4: J8.5, U8.14 (O5)
/PB5: J8.6, U8.13 (O6)
/PB6: J8.7, U8.12 (O7)
/PB7: J8.8, U8.11 (O8)
/PIOCE: U4.4 (~CE), U9.14 (O1)
/PIOIEI: U4.24 (IEI), U6.11 (IEO)
/RAMCE: U5.20 (~CE), U7.5 (Y1)
/RD: J1.7, U1.21 (~RD), U2.32 (~RD), U3.22 (~OE), U4.35 (~RD), U5.22 (~OE), U6.6 (~RD)
/RFSH: J4.4, U1.28 (~RFSH)
/ROMCE: U3.20 (~CS), U7.4 (Y0)
/RST: J1.12, R4.1, SW1.2, U1.26 (~RESET), U2.21 (~RESET), U6.17 (~RESET)
/RTSA: R6.2, U2.17 (~RTSA)
/RTSB: R17.2, U2.24 (~RTSB)
/RXA: R8.2, U2.12 (RxDA)
/RXB: JP1.1 (A), R19.2, U2.28 (RxDB)
/SIOCE: U2.35 (~CE), U9.15 (O0)
/SIOIEI: U2.6 (IEI), U4.22 (IEO)
/TXA: R9.2, U2.15 (TxDA)
/TXB: JP2.1 (A), R20.2, U2.26 (TxDB)
/USR1: J1.4
/USR2: J1.3
/USR3: J1.2
/USR4: J1.1
/WAIT: J4.5, R14.2, U1.24 (~WAIT)
/WR: J1.9, U1.22 (~WR), U5.27 (~WE)
/ZT0: J5.2, U6.7 (ZC/TO0)
/ZT1: J5.4, U6.8 (ZC/TO1)
/ZT2: J5.6, U6.9 (ZC/TO2)
GND: C1.2, C2.2, C3.2, C4.2, C5.2, C6.2, C7.2, C8.2, C9.2, C10.2, C11.2, C12.2, J1.23, J3.2, J3.3, J4.9, J5.8, J6.1, J7.10, J9.1, R1.1, R2.1, R3.1, R5.1, R16.1, R22.1, SW1.1, U1.29 (GND), U2.19 (~DCDA), U2.22 (~DCDB), U2.31 (GND), U3.14 (GND), U4.11 (GND), U5.14 (GND), U6.5 (GND), U7.3 (A1), U7.8 (GND), U8.9 (GND), U9.8 (GND), X1.4 (GND), X2.4 (GND); also elsewhere on the board
unnamed: D1.1 (K), R3.2
unnamed: D2.1 (K), R5.2
unnamed: J1.5, JP1.2 (B)
unnamed: J1.6, JP2.2 (B)
unnamed: J6.2, R6.1
unnamed: J6.3, JP5.2 (B)
unnamed: J6.4, R7.1, R8.1
unnamed: J6.5, R9.1
unnamed: J6.6, R10.1, R16.2
unnamed: J9.2, R17.1
unnamed: J9.3, JP6.2 (B)
unnamed: J9.4, R18.1, R19.1
unnamed: J9.5, R20.1
unnamed: J9.6, R21.1, R22.2
unnamed: JP3.1 (A), X1.5 (OUT)
unnamed: R1.2, U2.11 (~SYNCA)
unnamed: R2.2, U2.29 (~SYNCB)
VCC: C1.1, C2.1, C3.1, C4.1, C5.1, C6.1, C7.1, C8.1, C9.1, C10.1, C11.1, C12.1, D1.2 (A), J1.24, J3.1, J4.1, J8.10, JP5.1 (A), JP6.1 (A), R4.2, R7.2, R11.1, R12.1, R13.1, R14.1, R15.1, R18.2, R23.1, R24.1, U1.11 (VCC), U2.9 (VCC), U3.27 (~WE), U3.28 (VCC), U4.26 (VCC), U5.28 (VCC), U6.24 (VCC), U7.16 (VCC), U9.6 (E3), U9.16 (VCC), X1.1 (EN), X1.8 (Vcc), X2.1 (EN), X2.8 (Vcc)

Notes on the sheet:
Reset Switch
SIO
ZTO-80 Expansion Bus
PIO
PIO B Darlington Array
Decoupling Capacitors
RAM
Serial Connectors
ROM
CTC Header
CTS
Run LED
5V Input
I/O Addresses: SIO A D: $00 SIO B D: $01 SIO A C: $02 SIO B C: $03 PIO A D: $04 PIO B D: $05 PIO A C: $06 PIO B C: $07 CTC 0: $08 CTC 1: $09 CTC 2: $0A CTC 3: $0B
RAM/ROM Decoding
CPU
Memory Map: ROM: $0000-$7FFF RAM: $8000-$FFFF
CTC
Pull-up Resistors
GND
VCC
Power LED
System and Baud Clocks
RTS
I/O Decoding
PIO/CTC Headers
CPU Header

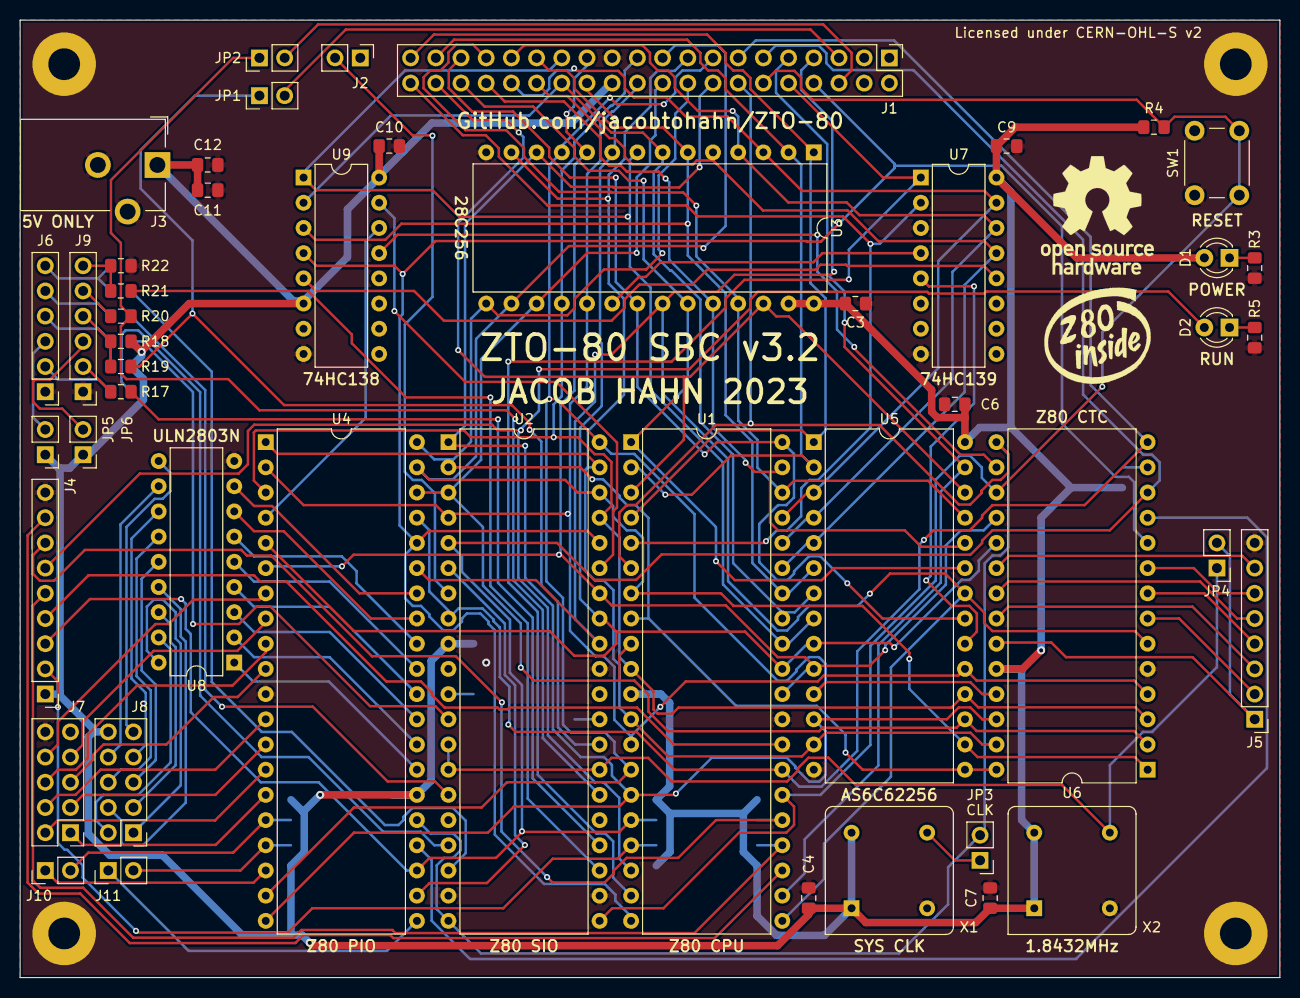
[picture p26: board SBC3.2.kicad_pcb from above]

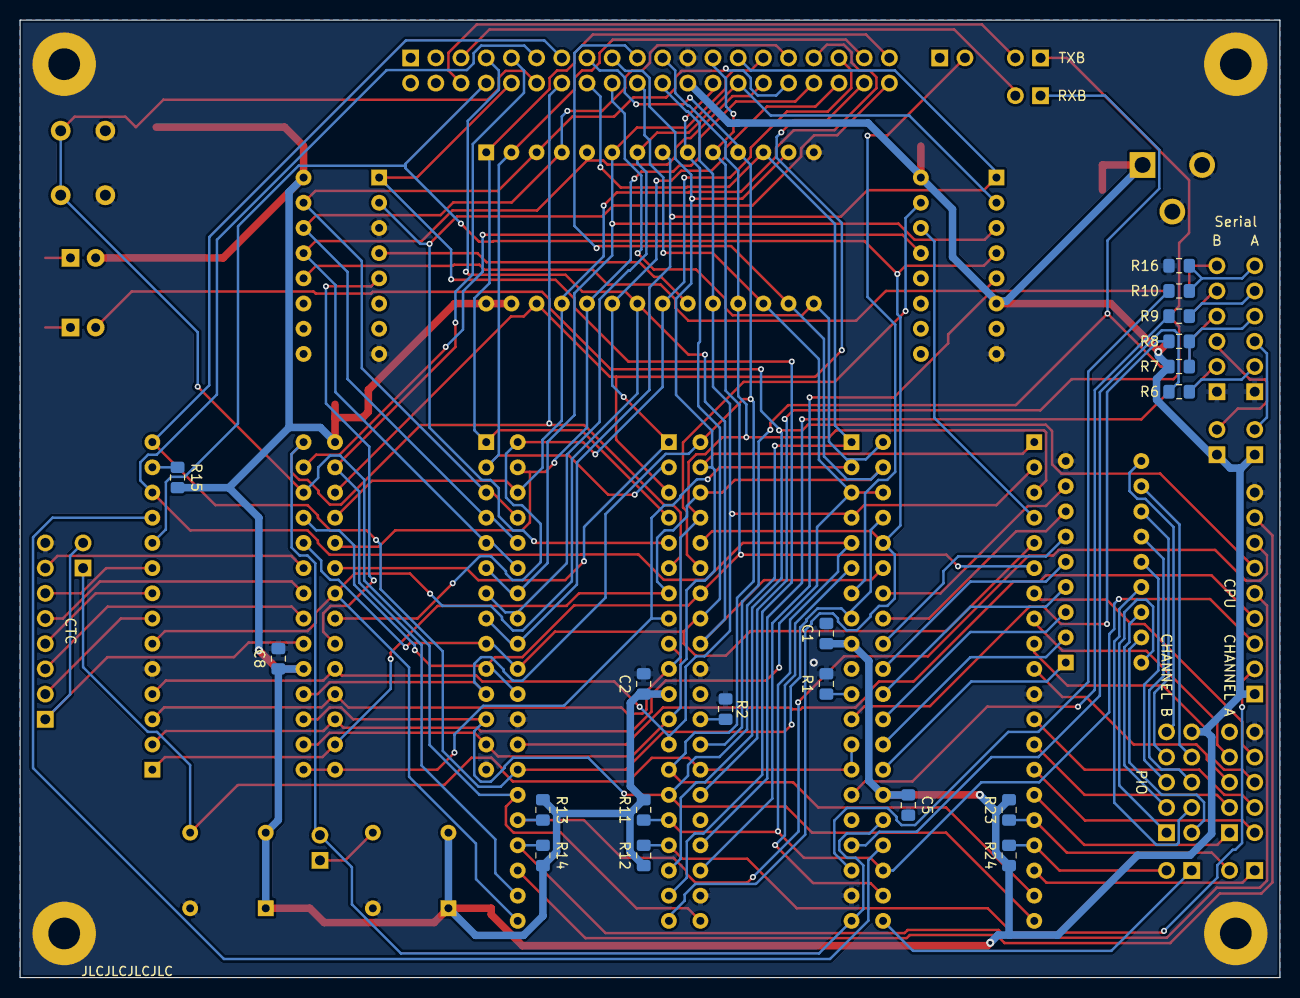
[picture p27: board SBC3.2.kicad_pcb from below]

Board: 2 copper layers, 127.0 x 96.5 mm, 71 parts (19 on the bottom side), 112 nets.

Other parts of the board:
Mount1, Mount2, Mount3, Mount4: MountingHole_3.2mm_M3_Pad

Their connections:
GND: Mount1.1, Mount2.1, Mount3.1, Mount4.1; also elsewhere on the board

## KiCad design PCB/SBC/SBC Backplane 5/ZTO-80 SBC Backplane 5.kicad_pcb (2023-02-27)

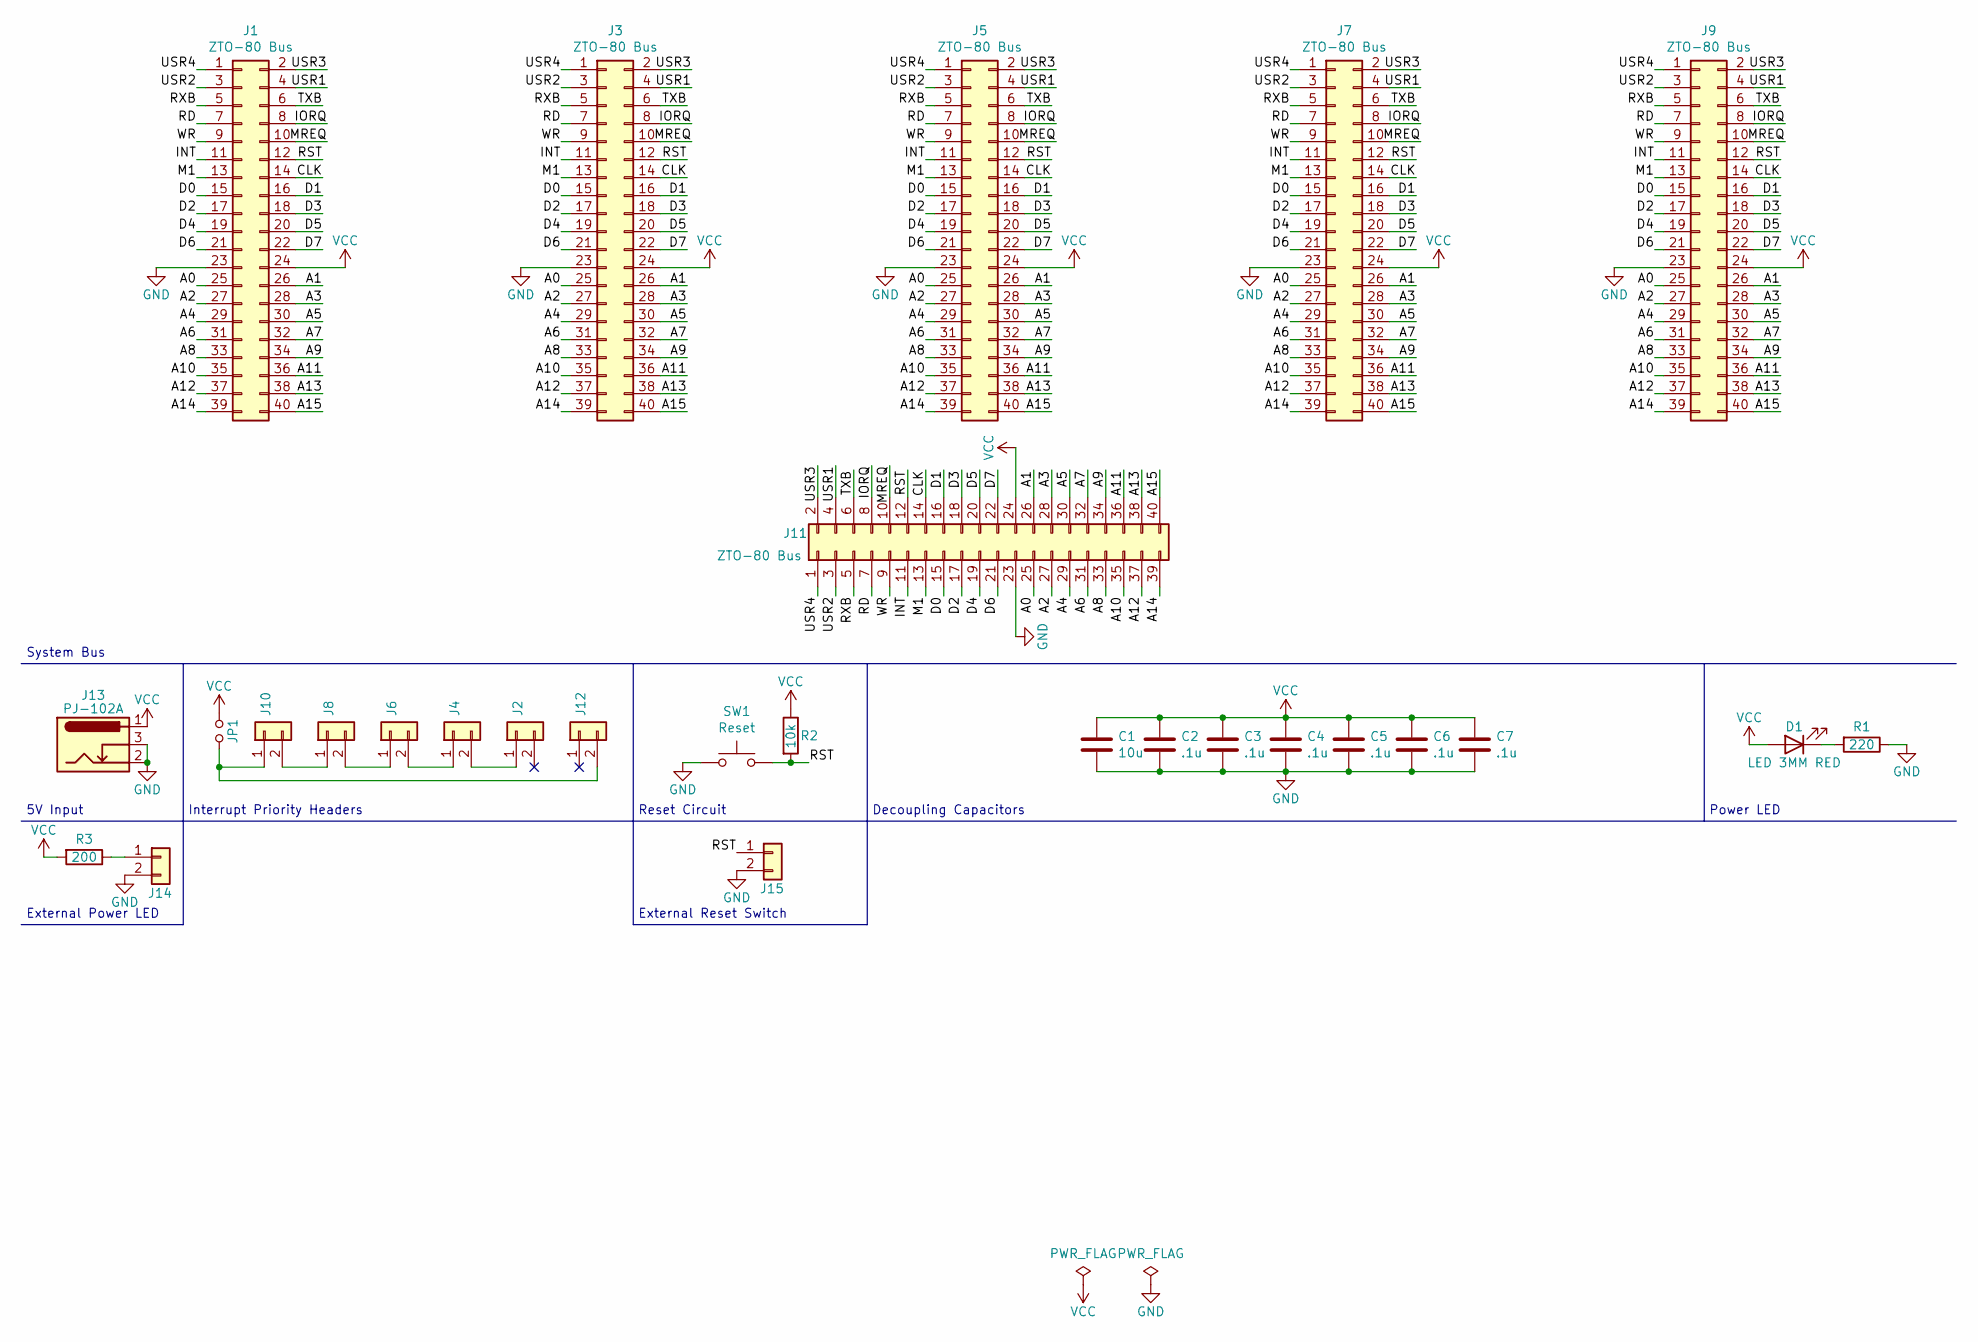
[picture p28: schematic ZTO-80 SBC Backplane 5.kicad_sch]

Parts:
C1: 10u; C_0805_2012Metric_Pad1.15x1.40mm_HandSolder
C2, C3, C4, C5, C6, C7: .1u; C_0805_2012Metric_Pad1.15x1.40mm_HandSolder
D1: LED 3MM RED; LED_D3.0mm
J1, J3, J5, J7, J9, J11: ZTO-80 Bus; PinSocket_2x20_P2.54mm_Vertical
J2, J4, J6, J8, J10, J12: Conn_01x02; PinSocket_2x01_P2.54mm_Vertical
J13: PJ-102A; BarrelJack_CUI_PJ-102A_Horizontal
J14, J15: Conn_01x02; PinHeader_1x02_P2.54mm_Vertical
JP1: Jumper_NO_Small; PinHeader_1x02_P2.54mm_Vertical
R1: 220; R_0805_2012Metric_Pad1.15x1.40mm_HandSolder
R2: 10k; R_0805_2012Metric_Pad1.15x1.40mm_HandSolder
R3: 200; R_0805_2012Metric_Pad1.15x1.40mm_HandSolder
SW1: Reset; SW_PUSH_6mm

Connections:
/A0: J1.25, J3.25, J5.25, J7.25, J9.25, J11.25
/A1: J1.26, J3.26, J5.26, J7.26, J9.26, J11.26
/A2: J1.27, J3.27, J5.27, J7.27, J9.27, J11.27
/A3: J1.28, J3.28, J5.28, J7.28, J9.28, J11.28
/A4: J1.29, J3.29, J5.29, J7.29, J9.29, J11.29
/A5: J1.30, J3.30, J5.30, J7.30, J9.30, J11.30
/A6: J1.31, J3.31, J5.31, J7.31, J9.31, J11.31
/A7: J1.32, J3.32, J5.32, J7.32, J9.32, J11.32
/A8: J1.33, J3.33, J5.33, J7.33, J9.33, J11.33
/A9: J1.34, J3.34, J5.34, J7.34, J9.34, J11.34
/A10: J1.35, J3.35, J5.35, J7.35, J9.35, J11.35
/A11: J1.36, J3.36, J5.36, J7.36, J9.36, J11.36
/A12: J1.37, J3.37, J5.37, J7.37, J9.37, J11.37
/A13: J1.38, J3.38, J5.38, J7.38, J9.38, J11.38
/A14: J1.39, J3.39, J5.39, J7.39, J9.39, J11.39
/A15: J1.40, J3.40, J5.40, J7.40, J9.40, J11.40
/CLK: J1.14, J3.14, J5.14, J7.14, J9.14, J11.14
/D0: J1.15, J3.15, J5.15, J7.15, J9.15, J11.15
/D1: J1.16, J3.16, J5.16, J7.16, J9.16, J11.16
/D2: J1.17, J3.17, J5.17, J7.17, J9.17, J11.17
/D3: J1.18, J3.18, J5.18, J7.18, J9.18, J11.18
/D4: J1.19, J3.19, J5.19, J7.19, J9.19, J11.19
/D5: J1.20, J3.20, J5.20, J7.20, J9.20, J11.20
/D6: J1.21, J3.21, J5.21, J7.21, J9.21, J11.21
/D7: J1.22, J3.22, J5.22, J7.22, J9.22, J11.22
/INT: J1.11, J3.11, J5.11, J7.11, J9.11, J11.11
/IORQ: J1.8, J3.8, J5.8, J7.8, J9.8, J11.8
/M1: J1.13, J3.13, J5.13, J7.13, J9.13, J11.13
/MREQ: J1.10, J3.10, J5.10, J7.10, J9.10, J11.10
/RD: J1.7, J3.7, J5.7, J7.7, J9.7, J11.7
/RST: J1.12, J3.12, J5.12, J7.12, J9.12, J11.12, J15.1, R2.2, SW1.2
/RXB: J1.5, J3.5, J5.5, J7.5, J9.5, J11.5
/TXB: J1.6, J3.6, J5.6, J7.6, J9.6, J11.6
/USR1: J1.4, J3.4, J5.4, J7.4, J9.4, J11.4
/USR2: J1.3, J3.3, J5.3, J7.3, J9.3, J11.3
/USR3: J1.2, J3.2, J5.2, J7.2, J9.2, J11.2
/USR4: J1.1, J3.1, J5.1, J7.1, J9.1, J11.1
/WR: J1.9, J3.9, J5.9, J7.9, J9.9, J11.9
GND: C1.2, C2.2, C3.2, C4.2, C5.2, C6.2, C7.2, J1.23, J3.23, J5.23, J7.23, J9.23, J11.23, J13.2, J13.3, J14.2, J15.2, R1.1, SW1.1
unnamed: D1.1 (K), R1.2
unnamed: J2.1, J4.2
unnamed: J4.1, J6.2
unnamed: J6.1, J8.2
unnamed: J10.1, J12.2, JP1.2
unnamed: J8.1, J10.2
unnamed: J14.1, R3.1
VCC: C1.1, C2.1, C3.1, C4.1, C5.1, C6.1, C7.1, D1.2 (A), J1.24, J3.24, J5.24, J7.24, J9.24, J11.24, J13.1, JP1.1, R2.1, R3.2

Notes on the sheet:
Power LED
External Reset Switch
System Bus
External Power LED
Interrupt Priority Headers
5V Input
Decoupling Capacitors
Reset Circuit

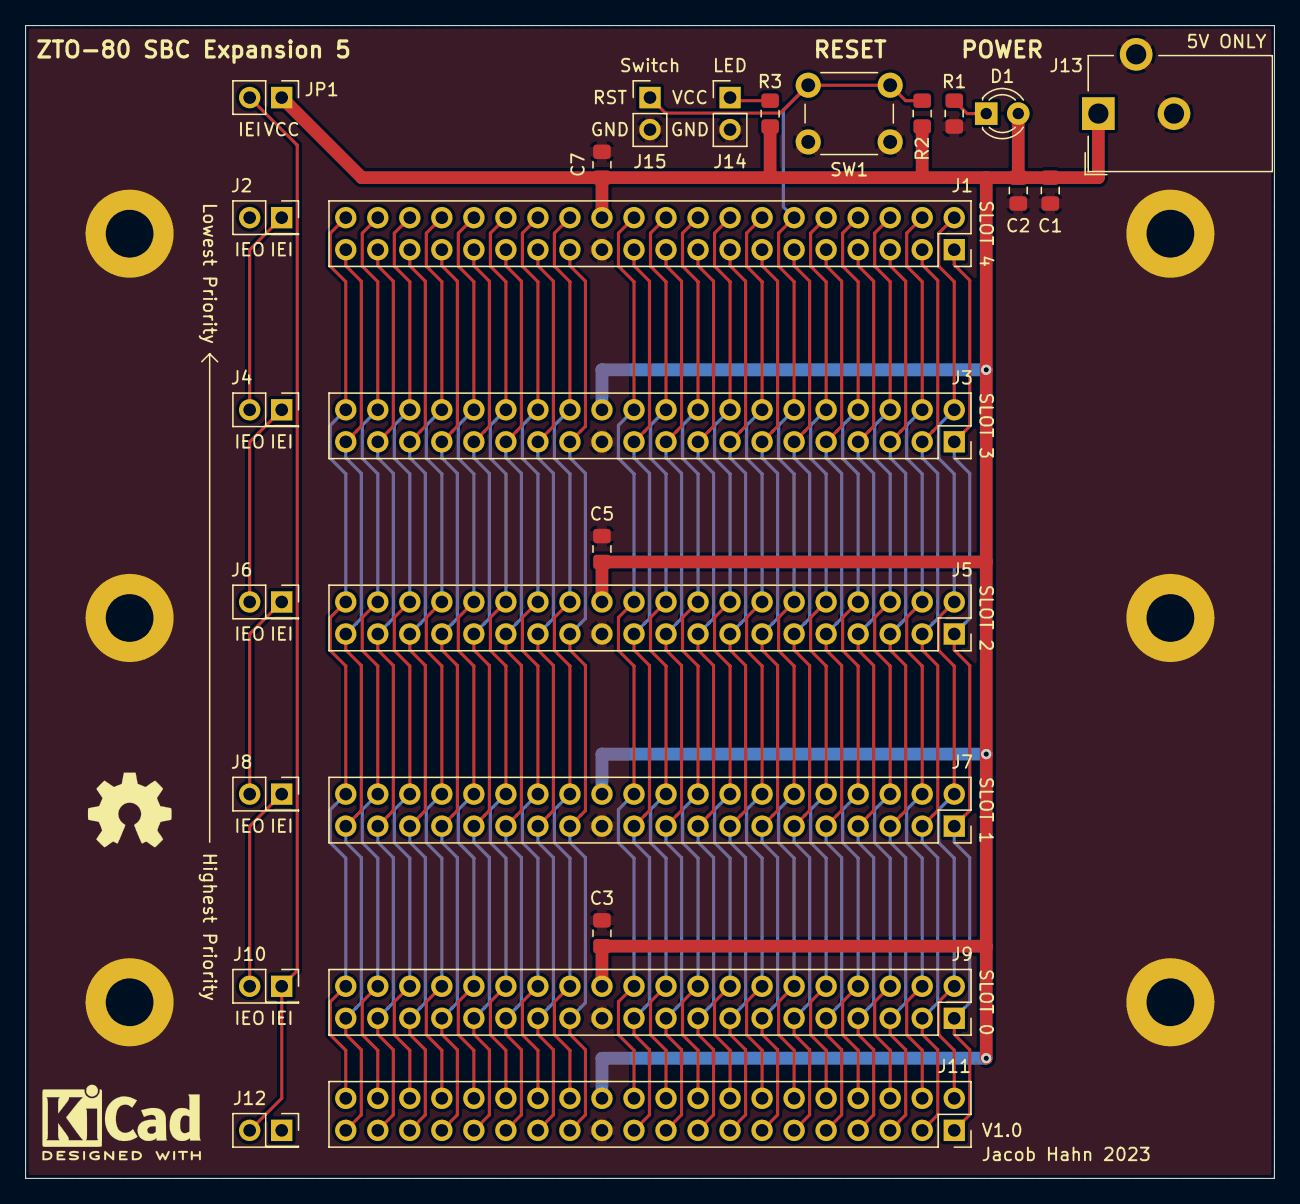
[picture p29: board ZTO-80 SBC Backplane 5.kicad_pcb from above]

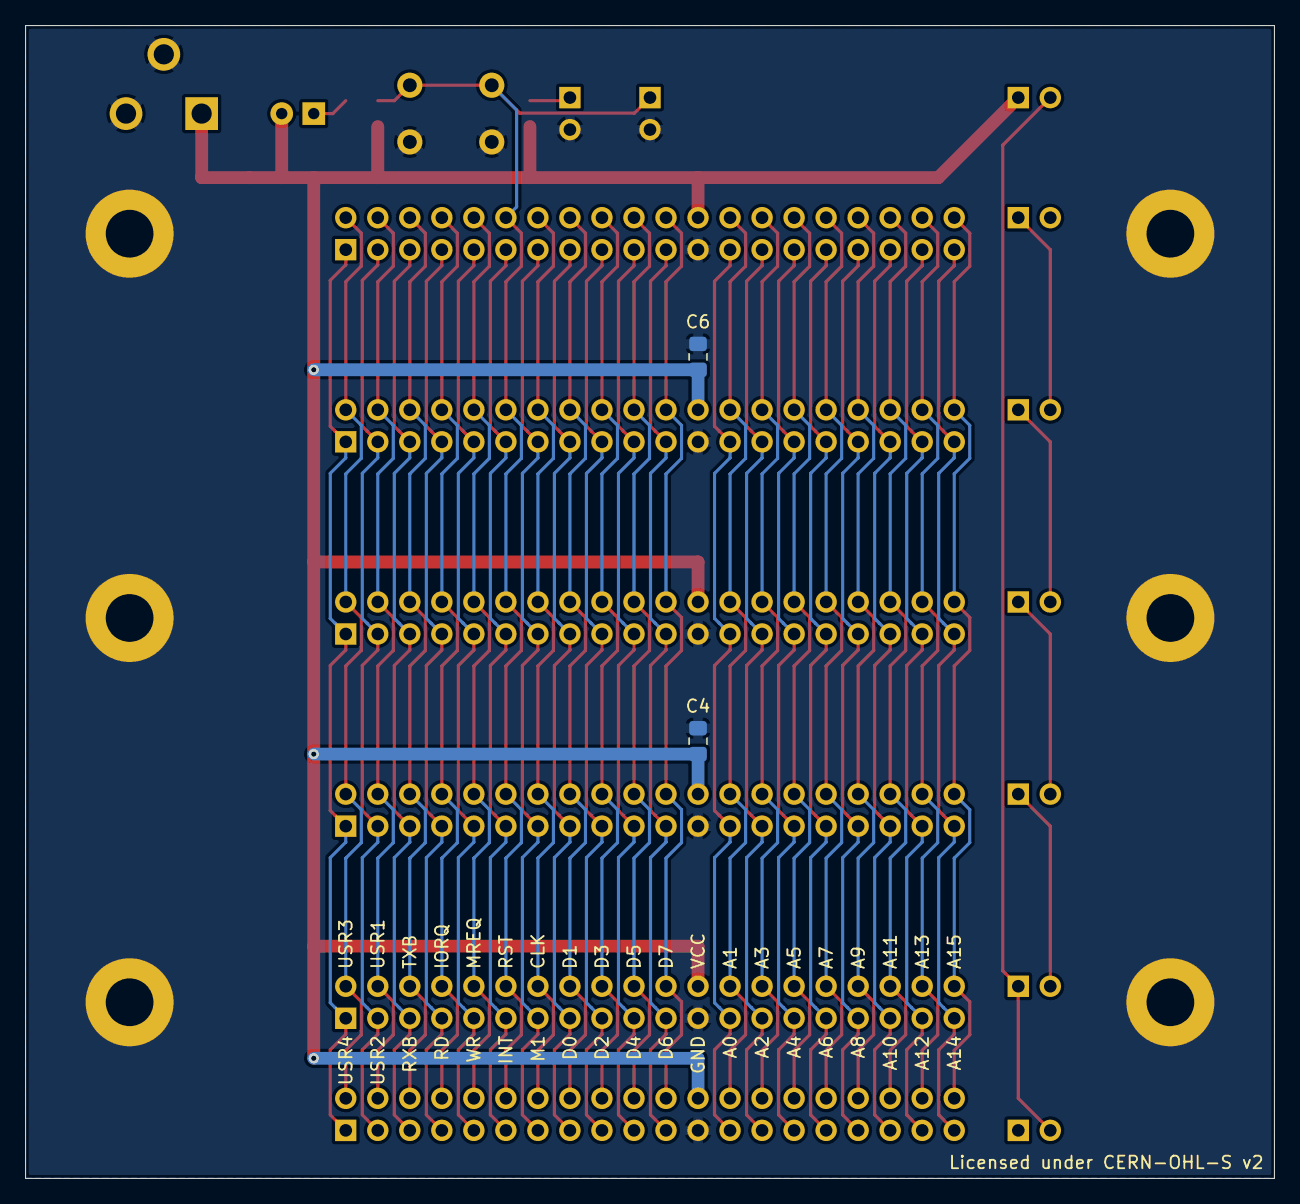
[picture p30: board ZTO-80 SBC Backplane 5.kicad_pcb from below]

Board: 2 copper layers, 99.1 x 91.4 mm, 28 parts (2 on the bottom side), 47 nets.

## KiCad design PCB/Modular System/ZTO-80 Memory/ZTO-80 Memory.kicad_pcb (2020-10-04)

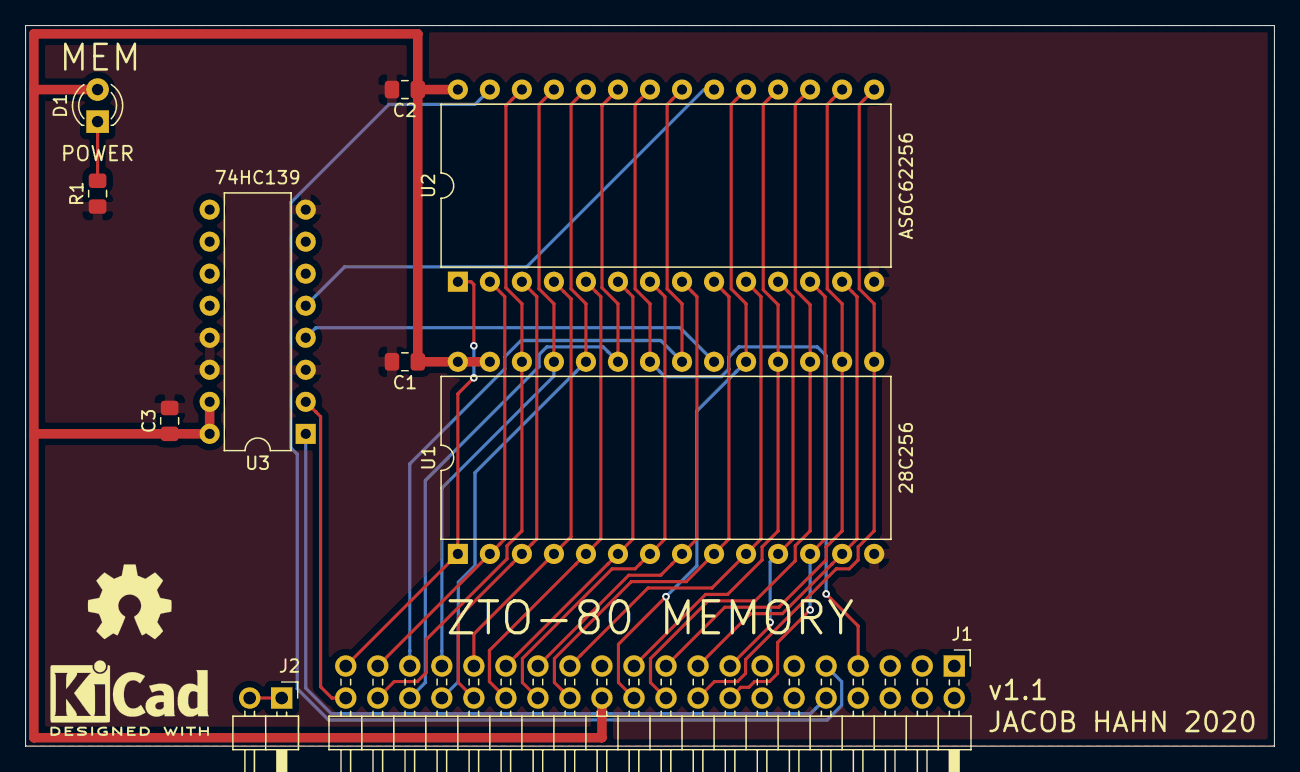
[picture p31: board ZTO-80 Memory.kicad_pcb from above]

Board: 2 copper layers, 99.1 x 57.1 mm, 10 parts (0 on the bottom side), 33 nets.

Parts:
C1, C2, C3: .1u; C_0805_2012Metric_Pad1.15x1.40mm_HandSolder
D1: LED 3MM RED; LED_D3.0mm
J1: ZTO-80 Bus; PinHeader_2x20_P2.54mm_Horizontal
J2: Conn_01x02; PinHeader_1x02_P2.54mm_Horizontal
R1: 220; R_0805_2012Metric_Pad1.15x1.40mm_HandSolder
U1: 28C256; DIP-28_W15.24mm
U2: AS6C62256; DIP-28_W15.24mm
U3: 74HC139; DIP-16_W7.62mm

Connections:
/A0: J1.25, U1.10, U2.10
/A1: J1.26, U1.9, U2.9
/A2: J1.27, U1.8, U2.8
/A3: J1.28, U1.7, U2.7
/A4: J1.29, U1.6, U2.6
/A5: J1.30, U1.5, U2.5
/A6: J1.31, U1.4, U2.4
/A7: J1.32, U1.3, U2.3
/A8: J1.33, U1.25, U2.25
/A9: J1.34, U1.24, U2.24
/A10: J1.35, U1.21, U2.21
/A11: J1.36, U1.23, U2.23
/A12: J1.37, U1.2, U2.2
/A13: J1.38, U1.26, U2.26
/A14: J1.39, U1.1, U2.1
/A15: J1.40, U3.2
/D0: J1.15, U1.11, U2.11
/D1: J1.16, U1.12, U2.12
/D2: J1.17, U1.13, U2.13
/D3: J1.18, U1.15, U2.15
/D4: J1.19, U1.16, U2.16
/D5: J1.20, U1.17, U2.17
/D6: J1.21, U1.18, U2.18
/D7: J1.22, U1.19, U2.19
/IEI: J2.1, J2.2
/MREQ: J1.10, U3.1
/RAMCE: U2.20, U3.5
/RD: J1.7, U1.22, U2.22
/ROMCE: U1.20, U3.4
/WR: J1.9, U2.27
GND: C1.2, C2.2, C3.2, J1.23, R1.1, U1.14, U2.14, U3.3, U3.8, U3.13, U3.14
unnamed: D1.1, R1.2
VCC: C1.1, C2.1, C3.1, D1.2, J1.24, U1.27, U1.28, U2.28, U3.15, U3.16

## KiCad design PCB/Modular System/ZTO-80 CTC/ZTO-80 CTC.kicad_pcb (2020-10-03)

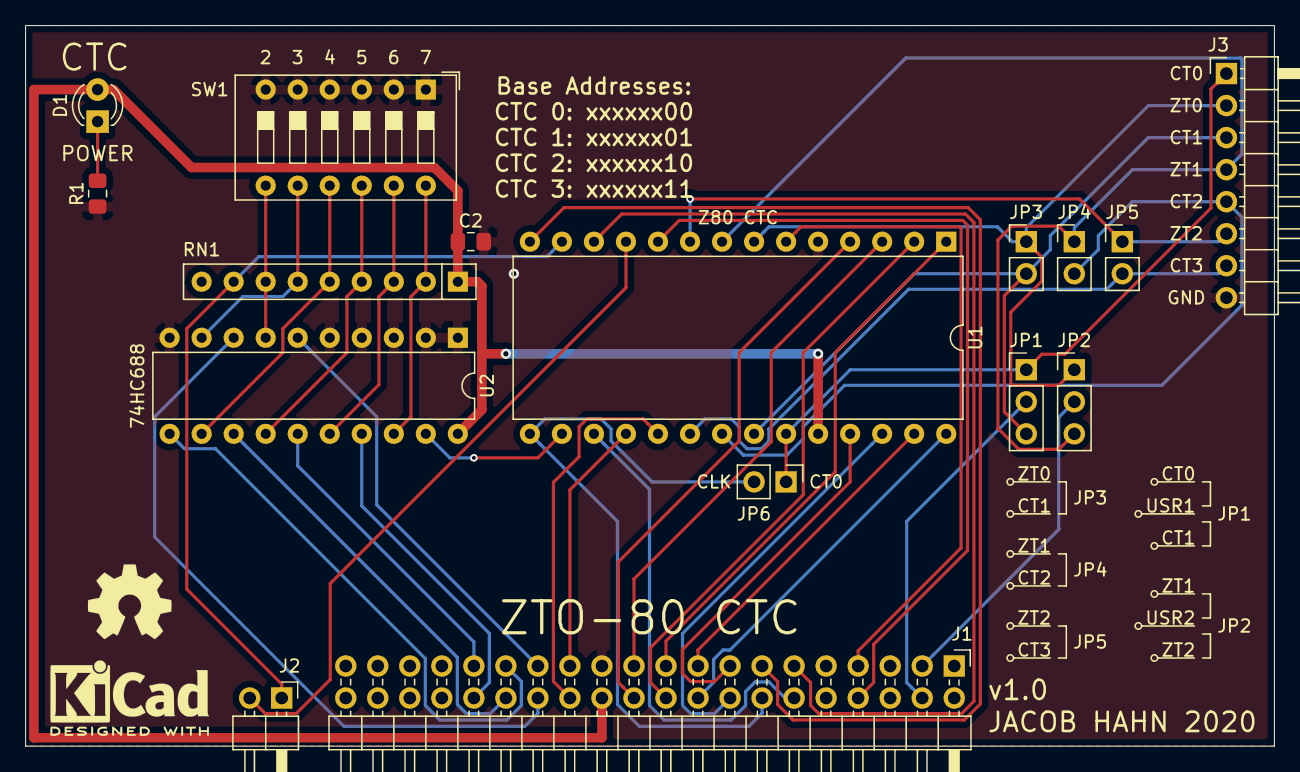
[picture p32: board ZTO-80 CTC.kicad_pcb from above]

Board: 2 copper layers, 99.1 x 57.1 mm, 17 parts (1 on the bottom side), 43 nets.

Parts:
C1, C2: .1u; C_0805_2012Metric_Pad1.15x1.40mm_HandSolder
D1: LED 3MM RED; LED_D3.0mm
J1: ZTO-80 Bus; PinHeader_2x20_P2.54mm_Horizontal
J2: Conn_01x02; PinHeader_1x02_P2.54mm_Horizontal
J3: Conn_01x08; PinHeader_1x08_P2.54mm_Horizontal
JP1, JP2: Jumper_3_Open; PinHeader_1x03_P2.54mm_Vertical
JP3, JP4, JP5, JP6: Jumper_2_Open; PinHeader_1x02_P2.54mm_Vertical
R1: 220; R_0805_2012Metric_Pad1.15x1.40mm_HandSolder
RN1: 10k; R_Array_SIP9
SW1: SW_DIP_x06; SW_DIP_SPSTx06_Slide_9.78x17.42mm_W7.62mm_P2.54mm
U1: Z80CTC; DIP-28_W15.24mm
U2: 74HC688; DIP-20_W7.62mm

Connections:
/A0: J1.25, U1.18
/A1: J1.26, U1.19
/A2: J1.27, U2.6
/A3: J1.28, U2.8
/A4: J1.29, U2.11
/A5: J1.30, U2.13
/A6: J1.31, U2.15
/A7: J1.32, U2.17
/CLK: J1.14, JP6.2, U1.15
/CT0: J3.1, JP1.1, JP6.1, U1.23
/CT1: J3.3, JP1.3, JP3.2, U1.22
/CT2: J3.5, JP4.2, U1.21
/CT3: J3.7, JP5.2, U1.20
/CTCCE: U1.16, U2.19
/CTCIEI: J2.1, RN1.8, U1.13
/D0: J1.15, U1.25
/D1: J1.16, U1.26
/D2: J1.17, U1.27
/D3: J1.18, U1.28
/D4: J1.19, U1.1
/D5: J1.20, U1.2
/D6: J1.21, U1.3
/D7: J1.22, U1.4
/IEO: J2.2, U1.11
/INT: J1.11, U1.12
/IORQ: J1.8, U1.10
/M1: J1.13, U1.14
/RD: J1.7, U1.6
/RST: J1.12, U1.17
/SQ2: RN1.7, SW1.7, U2.7
/SQ3: RN1.6, SW1.8, U2.9
/SQ4: RN1.5, SW1.9, U2.12
/SQ5: RN1.4, SW1.10, U2.14
/SQ6: RN1.3, SW1.11, U2.16
/SQ7: RN1.2, SW1.12, U2.18
/USR1: J1.4, JP1.2
/USR2: J1.3, JP2.2
/ZT0: J3.2, JP2.1, JP3.1, U1.7
/ZT1: J3.4, JP2.3, JP4.1, U1.8
/ZT2: J3.6, JP5.1, U1.9
GND: C1.2, C2.2, J1.23, J3.8, R1.1, SW1.1, SW1.2, SW1.3, SW1.4, SW1.5, SW1.6, U1.5, U2.1, U2.2, U2.3, U2.4, U2.5, U2.10
unnamed: D1.1, R1.2
VCC: C1.1, C2.1, D1.2, J1.24, RN1.1, U1.24, U2.20

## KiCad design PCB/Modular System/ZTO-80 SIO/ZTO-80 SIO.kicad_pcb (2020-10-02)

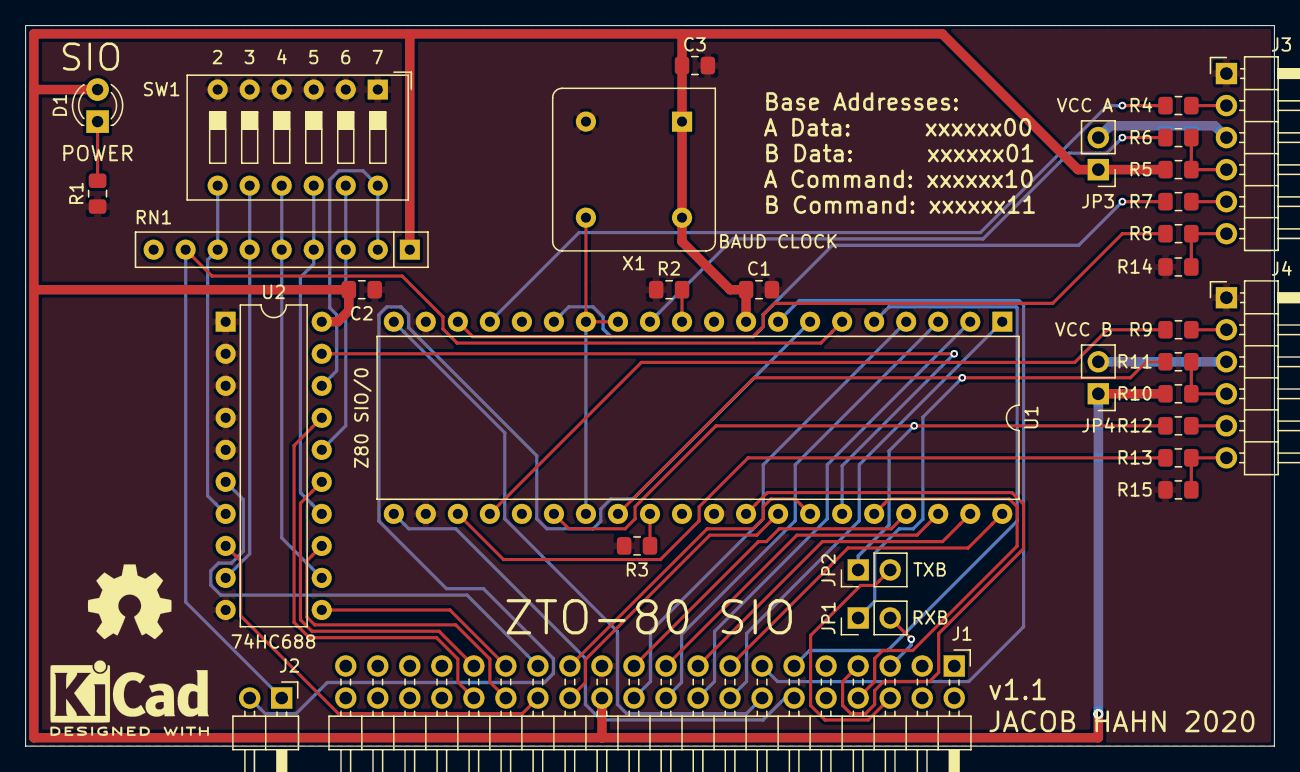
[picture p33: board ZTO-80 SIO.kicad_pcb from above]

Board: 2 copper layers, 99.1 x 57.1 mm, 32 parts (0 on the bottom side), 57 nets.

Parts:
C1, C2, C3: .1u; C_0805_2012Metric_Pad1.15x1.40mm_HandSolder
D1: LED 3MM RED; LED_D3.0mm
J1: ZTO-80 Bus; PinHeader_2x20_P2.54mm_Horizontal
J2: Conn_01x02; PinHeader_1x02_P2.54mm_Horizontal
J3, J4: SIOHDR; PinHeader_1x06_P2.54mm_Horizontal
JP1, JP2: Jumper_NC_Small; PinHeader_1x02_P2.54mm_Vertical
JP3, JP4: Jumper_2_Open; PinHeader_1x02_P2.54mm_Vertical
R1: 220; R_0805_2012Metric_Pad1.15x1.40mm_HandSolder
R2, R3: 10k; R_0805_2012Metric_Pad1.15x1.40mm_HandSolder
R4, R6, R7, R8, R9, R11, R12, R13: 2.2k; R_0805_2012Metric_Pad1.15x1.40mm_HandSolder
R5, R10, R14, R15: 100k; R_0805_2012Metric_Pad1.15x1.40mm_HandSolder
RN1: R_Network08; R_Array_SIP9
SW1: SW_DIP_x06; SW_DIP_SPSTx06_Slide_9.78x17.42mm_W7.62mm_P2.54mm
U1: Z80SIO0; DIP-40_W15.24mm
U2: 74HC688; DIP-20_W7.62mm
X1: 1.8432MHz; Oscillator_DIP-8

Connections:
/A0: J1.25, U1.34
/A1: J1.26, U1.33
/A2: J1.27, U2.6
/A3: J1.28, U2.8
/A4: J1.29, U2.11
/A5: J1.30, U2.13
/A6: J1.31, U2.15
/A7: J1.32, U2.17
/BCLK: U1.13, U1.14, U1.27, X1.5
/CLK: J1.14, U1.20
/CTSA: R8.2, U1.18
/CTSB: R13.2, U1.23
/D0: J1.15, U1.40
/D1: J1.16, U1.1
/D2: J1.17, U1.39
/D3: J1.18, U1.2
/D4: J1.19, U1.38
/D5: J1.20, U1.3
/D6: J1.21, U1.37
/D7: J1.22, U1.4
/IEI: J2.1, RN1.8, U1.6
/IEO: J2.2, U1.7
/INT: J1.11, U1.5
/IORQ: J1.8, U1.36
/M1: J1.13, U1.8
/RD: J1.7, U1.32
/RST: J1.12, U1.21
/RTSA: R4.2, U1.17
/RTSB: R9.2, U1.24
/RXA: R6.2, U1.12
/RXB: JP1.1, R11.2, U1.28
/SIOCE: U1.35, U2.19
/TXA: R7.2, U1.15
/TXB: JP2.1, R12.2, U1.26
GND: C1.2, C2.2, C3.2, J1.23, J3.1, J4.1, R1.1, R2.1, R3.1, R14.1, R15.1, SW1.1, SW1.2, SW1.3, SW1.4, SW1.5, SW1.6, U1.19, U1.22, U1.31, U2.1, U2.2, U2.3, U2.4, U2.5, U2.10, X1.4
unnamed: D1.1, R1.2
unnamed: J1.5, JP1.2
unnamed: J1.6, JP2.2
unnamed: J3.2, R4.1
unnamed: J3.3, JP3.2
unnamed: J3.4, R5.1, R6.1
unnamed: J3.5, R7.1
unnamed: J3.6, R8.1, R14.2
unnamed: J4.2, R9.1
unnamed: J4.3, JP4.2
unnamed: J4.4, R10.1, R11.1
unnamed: J4.5, R12.1
unnamed: J4.6, R13.1, R15.2
unnamed: R2.2, U1.11
unnamed: R3.2, U1.29
unnamed: RN1.2, SW1.12, U2.18
unnamed: RN1.3, SW1.11, U2.16
unnamed: RN1.4, SW1.10, U2.14
unnamed: RN1.5, SW1.9, U2.12
unnamed: RN1.6, SW1.8, U2.9
unnamed: RN1.7, SW1.7, U2.7
VCC: C1.1, C2.1, C3.1, D1.2, J1.24, JP3.1, JP4.1, R5.2, R10.2, RN1.1, U1.9, U2.20, X1.1, X1.8

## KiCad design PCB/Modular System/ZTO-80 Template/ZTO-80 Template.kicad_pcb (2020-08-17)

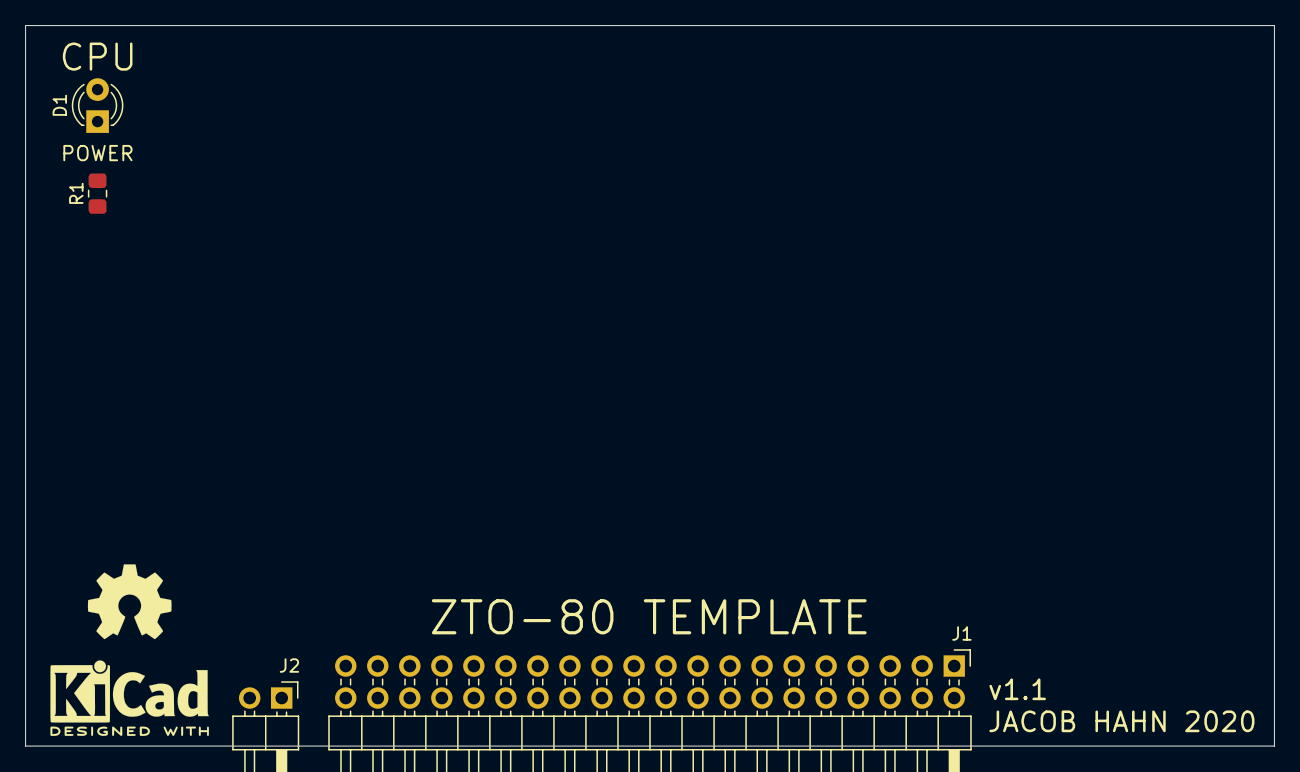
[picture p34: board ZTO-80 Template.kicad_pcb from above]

Board: 2 copper layers, 99.1 x 57.1 mm, 4 parts (0 on the bottom side), 3 nets, no tracks yet.

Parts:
D1: LED 3MM RED; LED_D3.0mm
J1: ZTO-80 Bus; PinHeader_2x20_P2.54mm_Horizontal
J2: Conn_01x02; PinHeader_1x02_P2.54mm_Horizontal
R1: 220; R_0805_2012Metric_Pad1.15x1.40mm_HandSolder

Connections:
GND: J1.23, R1.1
unnamed: D1.1, R1.2
VCC: D1.2, J1.24

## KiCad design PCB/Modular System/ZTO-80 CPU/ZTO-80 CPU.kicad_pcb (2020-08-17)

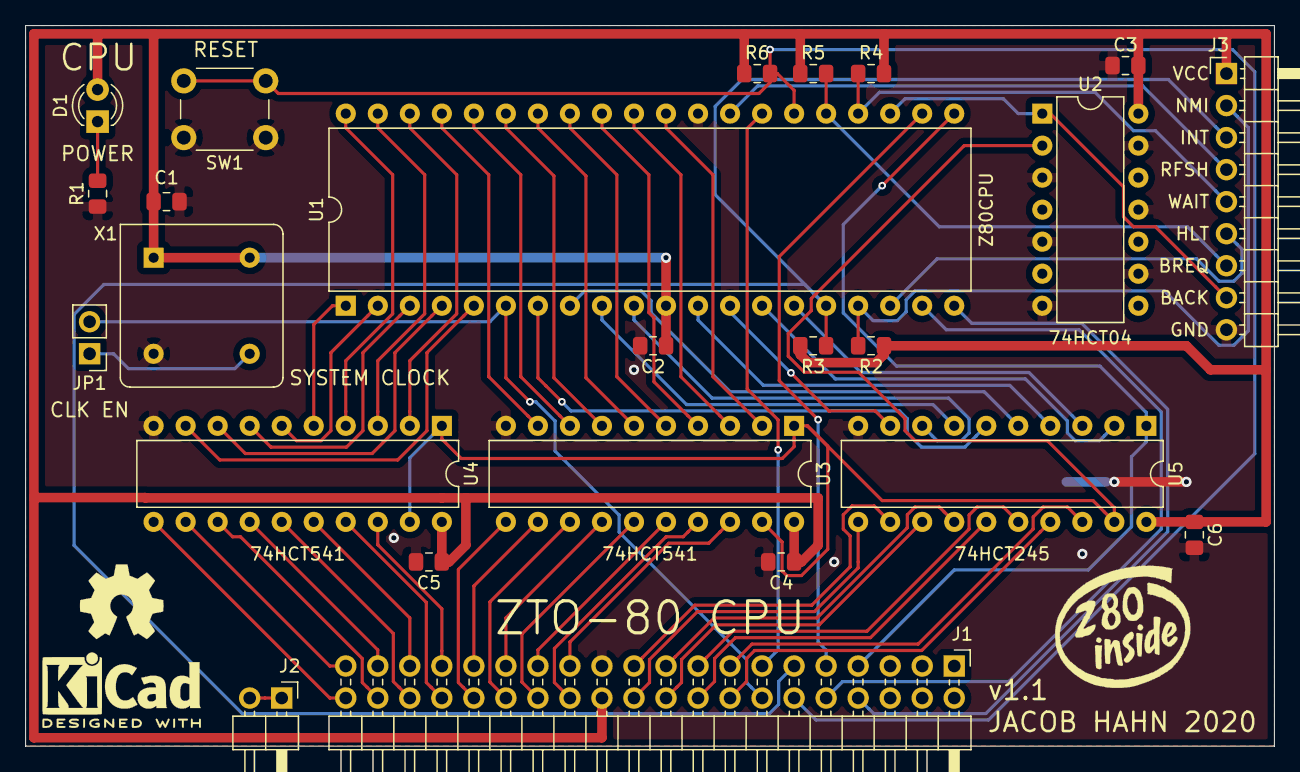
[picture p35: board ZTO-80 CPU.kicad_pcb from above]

Board: 2 copper layers, 99.1 x 57.1 mm, 24 parts (0 on the bottom side), 68 nets.

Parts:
C1, C2, C3, C4, C5, C6: 100nF; C_0805_2012Metric_Pad1.15x1.40mm_HandSolder
D1: LED 3MM RED; LED_D3.0mm
J1: ZTO-80 Bus; PinHeader_2x20_P2.54mm_Horizontal
J2: Conn_01x02; PinHeader_1x02_P2.54mm_Horizontal
J3: Conn_01x09; PinHeader_1x09_P2.54mm_Horizontal
JP1: Jumper_2_Bridged; PinHeader_1x02_P2.54mm_Vertical
R1: 220; R_0805_2012Metric_Pad1.15x1.40mm_HandSolder
R2, R3, R4, R5, R6: 10k; R_0805_2012Metric_Pad1.15x1.40mm_HandSolder
SW1: SW_Push; SW_PUSH_6mm
U1: Z80CPU; DIP-40_W15.24mm
U2: 74HCT04; DIP-14_W7.62mm
U3, U4: 74HCT541; DIP-20_W7.62mm
U5: 74HCT245; DIP-20_W7.62mm
X1: CXO_DIP8; Oscillator_DIP-8

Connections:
/A0: J1.25, U3.18
/A1: J1.26, U3.17
/A2: J1.27, U3.16
/A3: J1.28, U3.15
/A4: J1.29, U3.14
/A5: J1.30, U3.13
/A6: J1.31, U3.12
/A7: J1.32, U3.11
/A8: J1.33, U4.18
/A9: J1.34, U4.17
/A10: J1.35, U4.16
/A11: J1.36, U4.15
/A12: J1.37, U4.14
/A13: J1.38, U4.13
/A14: J1.39, U4.12
/A15: J1.40, U4.11
/BACK: J3.8, U1.23, U2.1
/BREQ: J3.7, R5.2, U1.25
/CLK: J1.14, JP1.2, U1.6
/D0: J1.15, U5.18
/D1: J1.16, U5.17
/D2: J1.17, U5.16
/D3: J1.18, U5.15
/D4: J1.19, U5.14
/D5: J1.20, U5.13
/D6: J1.21, U5.12
/D7: J1.22, U5.11
/HLT: J3.6, U1.18
/IEI: J2.1, J2.2
/INT: J1.11, J3.3, R3.2, U1.16
/IORQ: J1.8, U1.20
/M1: J1.13, U1.27
/MREQ: J1.10, U1.19
/NMI: J3.2, R2.2, U1.17
/RD: J1.7, U1.21, U5.1
/RFSH: J3.4, U1.28
/RST: J1.12, R6.2, SW1.2, U1.26
/WAIT: J3.5, R4.2, U1.24
/WR: J1.9, U1.22
/bufA0: U1.30, U3.2
/bufA1: U1.31, U3.3
/bufA2: U1.32, U3.4
/bufA3: U1.33, U3.5
/bufA4: U1.34, U3.6
/bufA5: U1.35, U3.7
/bufA6: U1.36, U3.8
/bufA7: U1.37, U3.9
/bufA8: U1.38, U4.2
/bufA9: U1.39, U4.3
/bufA10: U1.40, U4.4
/bufA11: U1.1, U4.5
/bufA12: U1.2, U4.6
/bufA13: U1.3, U4.7
/bufA14: U1.4, U4.8
/bufA15: U1.5, U4.9
/bufD0: U1.14, U5.2
/bufD1: U1.15, U5.3
/bufD2: U1.12, U5.4
/bufD3: U1.8, U5.5
/bufD4: U1.7, U5.6
/bufD5: U1.9, U5.7
/bufD6: U1.10, U5.8
/bufD7: U1.13, U5.9
/~BACK: U2.2, U3.1, U3.19, U4.1, U4.19, U5.19
GND: C1.2, C2.2, C3.2, C4.2, C5.2, C6.2, J1.23, J3.9, R1.1, SW1.1, U1.29, U2.3, U2.5, U2.7, U2.9, U2.11, U2.13, U3.10, U4.10, U5.10, X1.4
unnamed: D1.1, R1.2
unnamed: JP1.1, X1.5
VCC: C1.1, C2.1, C3.1, C4.1, C5.1, C6.1, D1.2, J1.24, J3.1, R2.1, R3.1, R4.1, R5.1, R6.1, U1.11, U2.14, U3.20, U4.20, U5.20, X1.1, X1.8

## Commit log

2020-08-02 Added PCB files and updated READMEs
    [ZTO-80 Backplane 5.kicad_pcb, ZTO-80 Backplane 5.sch, ZTO-80 CPU.kicad_pcb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]
2020-08-03 Edited power LED resistor value
    [ZTO-80 Backplane 5.kicad_pcb, ZTO-80 Backplane 5.sch, ZTO-80 CPU.kicad_pcb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]
2020-08-05 Update ZTO-80 CPU.kicad_pcb
    [ZTO-80 CPU.kicad_pcb]
2020-08-11 Added SBC
    [SBC.kicad_pcb, SBC.sch, SBC_BOM.csv]
2020-08-11 Deleted unnecessary PCB files
2020-08-11 Edit READMEs
    [ZTO-80 Template.kicad_pcb]
2020-08-14 Updates to PDFs and the SBC
    [SBC.kicad_pcb, SBC.sch, SBC_BOM.csv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]
2020-08-16 Net name update for SBC
    [SBC.kicad_pcb, SBC.sch]
2020-08-17 Changed bus orientation
    This change is backwards-compatible with all previous ZTO-80 modules
    [ZTO-80 Backplane 5.kicad_pcb, ZTO-80 Backplane 5.sch, ZTO-80 CPU.kicad_pcb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]
2020-08-17 Created ZTO-80 SIO
    [ZTO-80 SIO.kicad_pcb, ZTO-80 SIO.sch]
2020-08-17 Added CERN license text to silkscreen
    [ZTO-80 Backplane 5.kicad_pcb, ZTO-80 CPU.kicad_pcb, ZTO-80 CTC.kicad_pcb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]
2020-08-18 Updated SBC and added releases folder
    [SBC.kicad_pcb, SBC.sch, SBC_BOM.csv]
2020-09-01 Updated SBC to v3.1
    [SBC.kicad_pcb, SBC.sch, SBC_BOM.csv]
2020-09-20 Small changes to SBC
    [SBC.kicad_pcb, SBC.sch]
2020-10-02 Finished SIO
    [ZTO-80 SIO.kicad_pcb, ZTO-80 SIO.sch]
2020-10-02 Finished Backplane
    [ZTO-80 Backplane 5.kicad_pcb]
2020-10-03 Finished CTC
    [ZTO-80 CTC.kicad_pcb, ZTO-80 CTC.sch]
2020-10-04 Finished Memory
    [ZTO-80 Memory.kicad_pcb]
2020-10-08 Updated Backplane
    [ZTO-80 Backplane 5.kicad_pcb, ZTO-80 Backplane 5.sch]
2021-05-20 Preparing directory structure for SBC v3.2
    [SBC.kicad_pcb, SBC.sch]
2021-05-20 Add SBC v3.2 files
    [SBC3.1.kicad_pcb, SBC3.1.sch, SBC3.2.kicad_pcb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]
2021-09-26 Changed SBC V3.2 files and added PDFs
    [SBC3.2.kicad_pcb, SBC3.2.sch]
2023-02-27 Updates to 3.2 and SBC Backplane
    [SBC3.2.kicad_pcb, SBC3.2.kicad_sch, SBC3.2.sch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]

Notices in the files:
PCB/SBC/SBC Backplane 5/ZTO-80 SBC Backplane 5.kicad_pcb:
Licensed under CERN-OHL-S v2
